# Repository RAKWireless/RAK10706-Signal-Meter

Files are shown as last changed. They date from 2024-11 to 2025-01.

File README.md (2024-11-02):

# RAK10706 Signal Meter
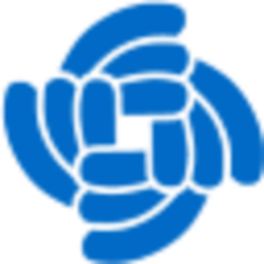
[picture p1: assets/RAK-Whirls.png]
RAKWireless
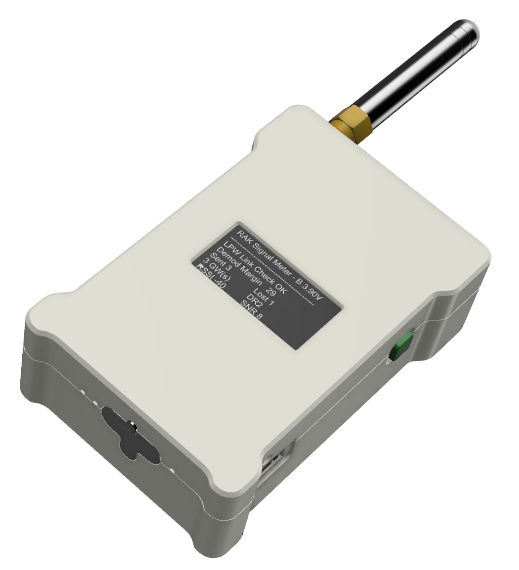
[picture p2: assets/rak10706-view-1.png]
Signal Meter
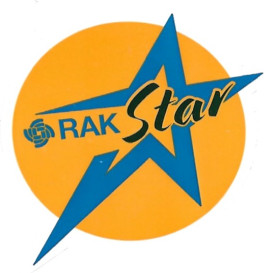
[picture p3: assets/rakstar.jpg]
RAKstar
|  |  |  | 
| :-: | :-: | :-: |

----

#### ⚠️ IMPORTANT ⚠️        
This firmware requires at least RUI3 V4.1.1 or newer.

#### ⚠️ ATTENTION ⚠️        
Requires the following Arduino libraries.

| Library | Get from Library Manager |
| --- | --- |
| ArduinoJSON version 6.x.x | http://librarymanager/All#ArduinoJson |
| SD | http://librarymanager/All#SD |
| Melopero RV3028 | http://librarymanager/All#RV3028 |
| Sparkfun LIS3DH | http://librarymanager/All#LIS3DH |
| Sparkfun u-Blox GNSS library | http://librarymanager/All#SparkFun_u-blox_GNSS |
| nRF OLED display | http://librarymanager/All#nRF52_OLED |
| CayenneLPP | http://librarymanager/All#CayenneLPP |

----

# Content
- [Overview](#overview)
- [Typical test scenarios](#typical-test-scenarios)
- [Custom AT commands](#custom-at-commands)
- [Hardware](#hardware)
- [Setup with built-in UI](#setup-with-built-in-ui)
- [Setup with AT commands](#setup-with-at-commands)
  - [LoRa P2P](#lora-p2p-setup)
  - [LoRaWAN LinkCheck](#lorawan-linkcheck-setup)
  - [LoRaWAN FieldTester (requires backend server)](#lorawan-field-tester-setup)
- [Usage](#usage)
  - [LoRa P2P](#lora-p2p)
  - [LoRaWAN LinkCheck](#lorawan-linkcheck)
  - [LoRaWAN FieldTester (requires backend server)](#lorawan-field-tester)
- [Log files (If SD card is present)](#log-files-if-sd-card-is-present)
  - [AT command for log files](#at-commands-for-log-files)
  - [Linkcheck mode log format](#linkcheck-mode-log-format)
  - [FieldTester mode log format](#field-tester-mode-log-format)
  - [P2P mode log format](#p2p-mode-log-format)
- [Enclosure](#enclosure)
- [Firmware](#firmware)

----

# Overview

The **RAK10706 Signal Meter for LoRa** is a basic signal meter. It works in both LoRa P2P and LoRaWAN mode. It uses an OLED display and a single-button controlled UI for settings changes. In addition, it can use an SD card to log the test results in CSV files. It is powered by a rechargeable battery and can be charged via USB Type-C interface.    
It uses an OLED display and a one-button controlled UI for settings changes. In addition, it can use an SD card to save the test results in .CSV files.   
All settings can be done as well over USB with RUI3 AT commands.    
It is a very easy to use device that can help to check LoRa and LoRaWAN coverage. It does not claim to be a super precise instrument, it is just an affordable small instrument to check signal coverage.    

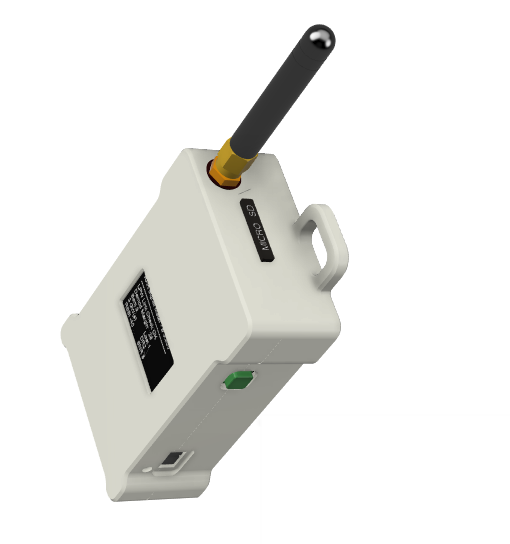
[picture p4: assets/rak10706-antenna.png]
Device internal
<center>Device&nbsp&nbsp&nbsp&nbsp</center>

#### ⚠️ INFO ⚠️        
One of the advantages of this simple tester is that it does not require any backend installations on the LoRaWAN server (like Helium, TTN and Chirpstack) if used in LinkCheck Packet mode, but should work with any LoRaWAN server like AWS or Actility.     
Only the FieldTester Mode requires a backend server.    

## LoRa P2P mode
If used in LoRa P2P, it is listening on the selected LoRa P2P settings and sending packets on the same settings:
- Frequency
- Bandwidth
- Spreading Factor
- Coding Rate
- Preample Length  

If a packet is received on above settings, it will display the information on the OLED screen. To use it for a specific P2P scenario, it will require adaption in the code, like recognizing packets, send out specific test packets to other LoRa P2P nodes.

## LoRaWAN mode
If used in LoRaWAN mode, the device is connecting to a LoRaWAN server and sends out frequently a data packet. 
It requires setup of the devices with its LoRaWAN credentials and register on a LoRaWAN server with
- DevEUI
- AppEUI
- AppKey
- OTAA join mode
- LoRaWAN region

### LoRaWAN Linkcheck test mode     
It uses LinkCheck to collect information about the connection to the gateway(s).    
With LinkCheck, the LoRaWAN server will report the number of gateways and the demodulation margin (calculated on the LoRaWAN server). The demodulation margin can give you information about the received signal quality (The higher the margin, the better the signal quality).     
Extract from the _**LoRaWAN 1.0.3 Specification**_:
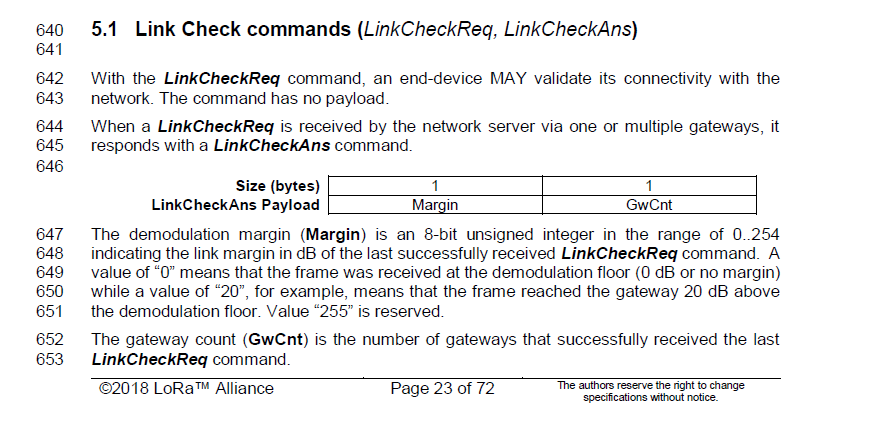
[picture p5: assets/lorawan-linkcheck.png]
LinkCheck


### LoRaWAN FieldTester test mode    
In addition, it supports the RAK10701 FieldTester protocol. The advantage of the FieldTester protocol is that it provides more information about the test, including distances to the gateways. The disadvantage is that this protocol requires a backend server to process the information and send it back to the device.

# Typical test scenarios
In all scenarios, tests can be performed in two ways:
- automatic sending in a specified interval. The interval can be set either through the built-in UI or with an AT command.
- forced sending. 3 times pushing the button enforces sending out a single packet in the pre-defined settings.
- forced sending with DR sweep (only in LoRaWAN test modes). 4 times pushing the button enforces multiple packets to be sent out. Sending starts with the lowest possible data rate and increases the data rate with each packet until the highest possible data rate has been reached.    

## Outdoor testing
In this scenario the location tracking should be enabled to add the tester location to the test results.    
The log files will contain the location of the tester at the time the test was performed. If no location fix could be acquired, the location will be set to Lat 0, Long 0.    

## Indoor testing
In this scenario the location tracking should be disabled, as the GNSS chip cannot aqcuire a valid location inside of buildings.    
The log files will not contain the location of the tester.

## LinkCheck testing
If it is not possible to connect a backend server to the LoRaWAN server to process the data of the received packets, the LinkCheck method should be used. It can deliver the basic information of the connection quality and if the tester is in the coverage range of gateways.

## FieldTester mode
If a backend server is connected to the LoRaWAN server that can process the data of the received packets, the FieldTester mode gives more details in the results of the test. 

## LoRa P2P testing
This is a very basic test that only shows whether the device is in range of another LoRa P2P device that is sending out packets.    

# Custom AT commands     
This examples includes multiple custom AT commands:     
- **`ATC+SENDINT`** to set the send interval time or heart beat time. The device will send a payload with this interval. The time is set in seconds, e.g. **`AT+SENDINT=600`** sets the send interval to 600 seconds or 10 minutes.    
- **`ATC+MODE`** to set the test mode. 0 using LPWAN LinkCheck, 1 using LoRa P2P, 2 using FieldTester protocol.
- **`ATC+STATUS`** to get some status information from the device.    
- **`ATC+PCKG`** to setup a custom payload that is used in the uplink packets.
- **`ATC+LOGS`** to retrieve or erase saved log files from the SD card (if SD card is present). See [AT command for log files](#at-commands-for-log-files)
- **`ATC+RTC`** to set or get time of RTC. Set format = [yyyy:mm:dd:hh:MM] (discard leading zeros!)

[Back to top](#content)

----

# Hardware
The device is built with a custom WisBlock Base Board:
- [WisBlock Base Board RAK19026 (WisMesh Base Board)](https://store.rakwireless.com/products/wismesh-baseboard-rak19026) ([Datasheet](https://docs.rakwireless.com/Product-Categories/Meshtastic/WisMesh-Base/Overview/))

To extend lifetime of the device, the battery can be disconnected by a simple slider switch. This helps to avoid discharging the battery while the device is not in use. The device can be charged, even with the button in off position!

The RAK19026 Base Board features as well a user configurable button, in this case it is used to control the UI, enable/disable the display and reset the device.

[Back to top](#content)

----

# Setup with built-in UI

Most of the parameters (not all) can be changed with the built-in UI.     
The UI has several levels, the navigation between the levels and selection of items is done with the single user button of the device.    

## Generic function of the button if the Settings UI is not active:

### Single click
==> no function

### Double click
==> enter the Settings UI (stops the testing mode, no more test packets are sent and received packets are ignored)

### 3 clicks
==> Force a downlink packet to be sent

### 4 clicks
==> Force multiple downlink packets with DR sweep. Sending starts with the lowest possible data rate and increases the data rate with each packet until the highest possible data rate has been reached.

### 5 clicks
==> no function (to avoid accidental reset of device)

### 6 clicks
==> Reset the device

### 7 clicks
==> Enter Bootloader Mode

### Long Press
==> switch off / on the display for power savings

## Function of the button if the Settings UI is active

The button function in the Settings UI changes, depending on the settings level. In general, a single click goes up one level in the settings.     
For other items, the number in front of the item indicates the number of clicks required to activate the level.    
If a level has selectable items, the selected items is marked with _**`(X)`**_ instead of its number.    
If a level has an item that can be toggled on/off, the status is shown after the item name.    

Overview of all settings levels and button functions:

| Level | Sub Level 1 | Sub Level 2 | Comment |
| ----- | --- | --- |--- |
| Top level<br> | | | Device might reset on leaving the settings if test mode has changed. |
| | Device Info <br> | | Current test settings |
| | Device Settings <br> | | General settings<br> Location and Display Saver are on/off toggle items<br><br>- Location on works only in FieldTester Mode and keeps the GNSS module powered up for faster location acquisition (faster battery drain)<br><br>- Display Saver on switches off the display after 1 minute. The display can be turned on with a single button click. |
| | | Send Interval <br> | Change send interval in 10 second steps<br>(2) 10 seconds more<br>(3) 10 seconds less |
| | Mode <br> | | Exclusive selection of one mode by number of clicks |
| | LoRa Settings (LoRaWAN test modes) <br> | | UI depends on selected test mode.<br> In LinkCheck, Confirmed Packet and FieldTester Mode, it shows LoRaWAN specific settings. |
| | | ADR on/off<br> | Switch ADR on or off |
| | | DR selection<br> | Change DR setting<br> (2) next higher DR<br>(3) next lower DR |
| | | TX Power selection<br> | Change TX power setting<br> (2) next higher TX power<br>(3) next lower TX power |
| | | LoRaWAN region selection<br> | Change LoRaWAN region setting<br> (2) next region<br>(3) previous region |
| | LoRa Settings (LoRa P2P test mode) <br> | | UI depends on selected test mode.<br> In LoRa P2P Mode, it shows LoRa P2P specific settings. |
| | | Frequency change<br> | Change send/receive frequency<br>(2) 0.1MHz up<br>(3) 0.1MHz down<br>For larger changes, it is recommended to use the AT commands. |
| | | SF change<br> | Change Spreading Factor<br>(2) next SF<br>(3) previous SF<br>For larger changes, it is recommended to use the AT commands. |
| | | BW change<br> | Change Bandwidth<br>(2) next BW<br>(3) previous BW |
| | | CR change<br> | Change Coding Rate<br>(2) next CR<br>(3) previous CR |
| | | TX power change<br> | Change Transmission Power<br>(2) next TX level <br>(3) previous TX level |

----

# Setup with AT commands

## LoRa P2P Setup

To use the device in LoRa P2P mode it has to be set into this mode with     
```at
AT+NWM=0
```
The device might reboot after this command, if it was not already in P2P mode.    
Then the LoRa P2P parameters have to be setup. In this example, I am setting the device to 916100000 Hz frequency, 125kHz bandwidth, spreading factor 7, coding rate 4/5, preamble length 8 and TX power of 5dBm:

```at
AT+PRECV=0
AT+P2P=916000000:7:0:1:8:5
ATC+MODE=2
```

#### ⚠️ TIP ⚠️ 
If the credentials were set already (they are saved in the flash of the device), the switch to P2P testing can as well be done with
```at
ATC+MODE=2
```
The device might reboot after this command, if it was not already in LoRa P2P mode.    

#### ⚠️ TIP ⚠️        
The command _**`AT+PRECV=0`**_ is _**required**_ to stop the device from listening. While in RX mode, parameters cannot be changed.

To be able to receive packets from other devices, they have to be setup to exactly the same parameters.

[Back to top](#content)

----

## LoRaWAN LinkCheck Setup

To use the device in LoRaWAN mode it has to be set into this mode with     
```at
AT+NWM=1
```
The device might reboot after this command, if it was not already in LoRaWAN mode.    
Then the LoRaWAN parameters and credentials have to be setup. In this example, I am setting the device to AS923-3, OTAA join mode, unconfirmed packet mode, enable link check and then reset the device to perform a LoRaWAN JOIN sequence:

```at
AT+BAND=10
AT+NJM=1
AT+CFM=0
AT+LINKCHECK=2
AT+DEVEUI=AC1F09FFFE000000
AT+APPEUI=AC1F09FFFE000000
AT+APPKEY=AC1F09FFFE000000AC1F09FFFE000000
ATC+MODE=0
ATZ
```

#### ⚠️ TIP ⚠️ 
If the credentials were set already (they are saved in the flash of the device), the switch to LinkCheck testing can as well be done with
```at
ATC+MODE=0
```
The device might reboot after this command, if it was not already in LoRaWAN mode.    

#### ⚠️ IMPORTANT ⚠️        
The device has to be registered in a LoRaWAN server with these credentials and a gateway in range has to be connected to the LoRaWAN server. Otherwise the device cannot join and there are no tests possible!
If the device cannot join the network, it will show an error on the display:

<center>LoRaWAN Join Failed</center>

In this case double check all settings on the device and LoRaWAN server and check if a gateway is in range and connected to the LoRaWAN server.

[Back to top](#content)

----

## LoRaWAN FieldTester Setup

To use the device in LoRaWAN mode it has to be set into this mode with     
```at
AT+NWM=1
```
The device might reboot after this command, if it was not already in LoRaWAN mode.    
Then the LoRaWAN parameters and credentials have to be setup. In this example, I am setting the device to AS923-3, OTAA join mode, confirmed packet mode, disable link check and then reset the device to perform a LoRaWAN JOIN sequence:

```at
AT+BAND=10
AT+NJM=1
AT+CFM=1
AT+LINKCHECK=0
AT+DEVEUI=AC1F09FFFE000000
AT+APPEUI=AC1F09FFFE000000
AT+APPKEY=AC1F09FFFE000000AC1F09FFFE000000
ATC+MODE=3
ATZ
```

#### ⚠️ TIP ⚠️ 
If the credentials were set already (they are saved in the flash of the device), the switch to FieldTester testing can as well be done with
```at
ATC+MODE=3
```
The device might reboot after this command, if it was not already in LoRaWAN mode.    

#### ⚠️ IMPORTANT ⚠️        
In FieldTester Mode a backend server has to be setup as integration in the LoRaWAN server. Without this backend server, the FieldTester Mode does not work.    
More information about available backend solutions can be found in the [RAK10701 documentation](https://docs.rakwireless.com/Product-Categories/WisNode/RAK10701-P/Quickstart/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)

#### ⚠️ IMPORTANT ⚠️        
The device has to be registered in a LoRaWAN server with these credentials and a gateway in range has to be connected to the LoRaWAN server. Otherwise the device cannot join and there are no tests possible!
If the device cannot join the network, it will show an error on the display:

<center>LoRaWAN Join Failed</center>

In this case double check all settings on the device and LoRaWAN server and check if a gateway is in range and connected to the LoRaWAN server.

[Back to top](#content)

----

# Usage
The principle usage for all modes is similar. After selecting the mode and setting the correct parameters and credentials, the device will send uplink packets in the selected send interval.    

#### ⚠️ IMPORTANT ⚠️        
When using FieldTester Mode, the device requires to have a valid location fix from it's builtin GNSS module. Otherwise it will not send any uplink packets.    

## LoRa P2P

If the setup of all devices is the same and a packet is received, the display will show the received LoRa P2P packets:

- P2P received packet number
- Frequency, spreading factor and bandwidth
- RSSI
- SNR

<center>LoRa P2P</center>

[Back to top](#content)

----

## LoRaWAN LinkCheck

After the device has joined the network, it will send unconfirmed packets with LinkCheck request enabled to the LoRaWAN server. The LoRaWAN server will answer to the LinkCheck request. The display will show
- Linkcheck result
- Packet number and number of gateways
- DR of the received packet
- RSSI and SNR of the received packet
- Demodulation Margin from the LoRaWAN server

<center>LoRaWAN ACK</center>

If the device is out of the range of gateways (after it had joined before), it will show an error message if the LoRaWAN server did respond to the LinkCheck request:
- Linkcheck result
- Number of lost packets

<center>LoRaWAN ACK</center>

[Back to top](#content)

----

## LoRaWAN FieldTester

After the device has joined the network, it will send confirmed packets with location information to the LoRaWAN server. The LoRaWAN server will forward this information together with gateway information to the backend server. The backend server will create and send a downlink packet to the tester. The display will show
- RSSI and SNR level of the received downlink packet
- Number of gateways that received the packet
- Min and Max RSSI levels seen by the gateways
- Min and Max calculated distance between the tester and the gateways
- Location of the device

<center>Fieldtester display</center>

Before sending a uplink packet, the tester will try to acquire a location.    

<center>Fieldtester location acquisition</center>

If a location fix can be acquired, it will send an uplink packet, then wait for the downlink packet from the backend server:

If no location fix can be acquired, an error will be displayed and no packet will be sent:

<center>Fieldtester location failure</center>

#### ⚠️ IMPORTANT ⚠️        
In FieldTester Mode a backend server has to be setup as integration in the LoRaWAN server. Without this backend server, the FieldTester Mode does not work.    
More information about available backend solutions can be found in the [RAK10701 documentation](https://docs.rakwireless.com/Product-Categories/WisNode/RAK10701-P/Quickstart/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)

[Back to top](#content)

----

# Log files (If SD card is present)

If a SD card is present, the results of the coverage tests are written in CSV format to the SD card.    
The files start from 0000-log.csv and on every restart a new file with an upcounting number is created.    

## AT commands for log files

_**`ATC+LOGS=?`**_ is used to retrieve the log files over the USB port. This makes it possible to read the log files without removing the SD card from the device.    

_**`ATC+LOGS=e`**_ is used to erase all log files from the SD card.    

----

## Linkcheck mode log format

When in Linkcheck mode for LoRaWAN, the log file has the following format:    

### If location is enabled

time;Mode;Gw;Lat;Lng;RX RSSI;RX SNR;Demod;TX DR;Lost

### If location is disabled

time;Mode;Gw;RX RSSI;RX SNR;Demod;TX DR;Lost

| time | Mode | Gw | Lat | Lng | RX RSSI | RX SNR | Demod | TX DR | Lost |
| ---  | ---  | --- | --- | --- | --- | --- | --- | ---  | ---  |
| Time stamp (available if LNS has provided the time or if a RTC module is attached) | 0 for LinkCheck mode | Number of gateways | Latitude (if location is active and location fix) | Longitude (if location is active and location fix) | RSSI of downlink | SNR of downlink | demod value | TX datarate | number of lost packets  |
| 2024-10-07 14:35:20 | 0 | 1 | 14.521355 | 121.106880 | -91 | 8 | 29 | 3 |0  |

----

## FieldTester mode log format

When in FieldTester mode for LoRaWAN, the log file has the following format:    

time;Mode;Gw;Lat;Lng;min RSSI;max RSSI;RX RSSI;RX SNR;min Dist;max Dist; TX DR

| time | Mode | Gw | Lat | Lng | min RSSI | max RSSI | RX RSSI | RX SNR | min Dist | max Dist | TX DR |
| ---  | ---  | --- | --- | --- | --- | --- | --- | --- | --- | --- | --- |
| Time stamp (available if LNS has provided the time or if a RTC module is attached) | 2 for FieldTester mode | Number of gateways | Latitude (can be 0.0 if no location fix, e.g. indoor testing) | Longitude (can be 0.0 if no location fix, e.g. indoor testing) | min RSSI seen by gateways | max RSSI seen by gateways | RSSI of downlink | SNR of downlink | min distance to gateway(s) | max distance to gateway(s) | TX datarate |
| 2024-10-07 14:39:00 | 2 | 1 | 14.521355 | 121.106880 | -50 | -50 | -59 | 7 | 250 | 250 | 5 |

----

## P2P mode log format

When in Linkcheck mode for LoRaWAN, the log file has the following format:    

### If location is enabled

time;Mode;Lat;Lng;RX RSSI;RX SNR

### If location is disabled

time;Mode;RX RSSI;RX SNR

| time | Mode | Lat | Lng | RX RSSI | RX SNR |
| ---  | ---  | --- | --- | --- | --- |
| Time stamp (available if LNS has provided the time or if a RTC module is attached) | 1 for LinkCheck mode | Latitude (if location is active and location fix) | Longitude (if location is active and location fix) | RSSI of downlink | SNR of downlink |
| 2024-10-07 14:51:21 | 1 | 14.521355 | 121.106880 | -38 | 12 |

----

# Enclosure

The enclosure is 3D printed and kept as simple as possible. Two main parts are needed. The bottom and the lid are sliding into each other to give a basic dust protection and are secured with four screws.    
In addition three smaller parts are used to give a dust protection to the user button, power switch and reset button. The LED's and the OLED screen can be protected by adding a thin transparent plastic foil.    
For the USB port and SD card slot rubber lids are used.    

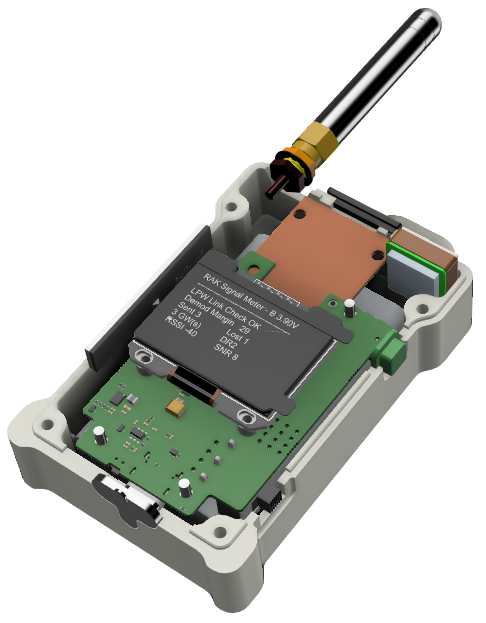
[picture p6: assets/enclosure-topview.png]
Enclosure Top View


The OLED display is part of the Base Board.    

The top and bottom part of the enclosure are overlapping to provide a simple sealing.

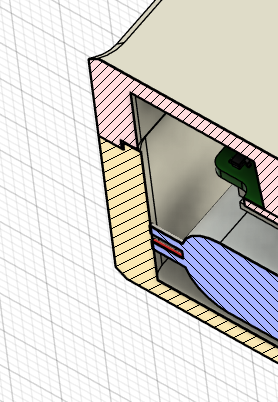
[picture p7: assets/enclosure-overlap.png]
Enclosure Sealing
    

The button of the RAK19026 is protected with additional 3D parts (green) against dust entry.

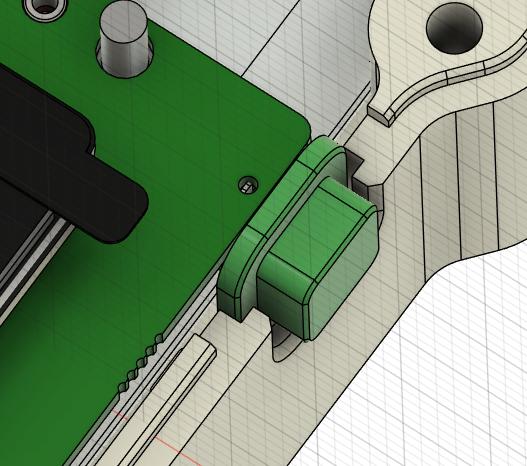
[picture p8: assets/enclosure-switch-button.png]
Enclosure Switch and Button
    

The enclosure provides enough space for a 3200mAh Li-Ion battery glued to the bottom.

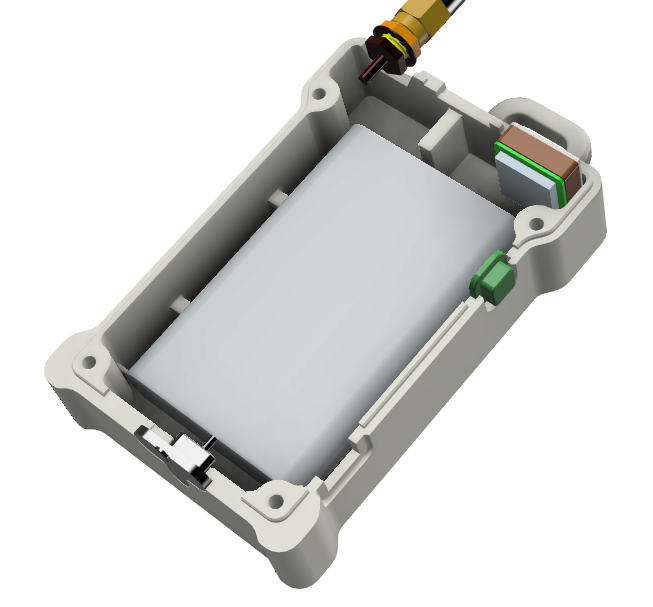
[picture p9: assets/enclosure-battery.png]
Enclosure Screws


#### ⚠️ TIP ⚠️        
The 3D files for the enclosure are available in this repository in the folder [enclosure](./enclosure) 

[Back to top](#content)

----

# Firmware

The firmware for this Signal Meter is available in this repository.

Callbacks are defined for all possible events, both LoRa P2P and LoRaWAN and trigger the display to change its content.

The **`setup()`**` function is checking in which mode the device is setup and initializes the required event callbacks.

The application is complete timer triggered and the **`loop()`** function is only used when the user button is used to check the number of clicks or to detect a long press of the button.

## LoRa P2P callbacks

```cpp
/**
 * @brief Receive callback for LoRa P2P mode
 *
 * @param data structure with RX packet information
 */
void recv_cb_p2p(rui_lora_p2p_recv_t data)
{}
```

## LoRaWAN callback

```cpp
/**
 * @brief Join network callback
 * 
 * @param status status of join request
 */
void join_cb_lpw(int32_t status)
{}

/**
 * @brief Receive callback for LoRaWAN mode
 *
 * @param data structure with RX packet information
 */
void recv_cb_lpw(SERVICE_LORA_RECEIVE_T *data)
{}

/**
 * @brief Send finished callback for LoRaWAN mode
 *
 * @param status
 */
void send_cb_lpw(int32_t status)
{}

/**
 * @brief Linkcheck callback
 * 
 * @param data structure with the result of the Linkcheck
 */
void linkcheck_cb_lpw(SERVICE_LORA_LINKCHECK_T *data)
{}
```

## LoRaWAN send
This function sends a short LoRaWAN packet in confirmed or unconfirmed mode, depending whether LinkCheck is enabled or not
```cpp
/**
 * @brief Send a LoRaWAN packet
 *
 * @param data unused
 */
void send_packet(void *data)
{
	Serial.println("Send packet");
	uint8_t payload[4] = {0x01, 0x02, 0x03, 0x04};

	api.lorawan.send(4, payload, 2, false);
	tx_active = true;
	}
}
```

## Display handler
The display handler callback includes a flag that tells what kind of display content should be displayed.
```cpp
/**
 * @brief Display handler
 *
 * @param reason 1 = RX packet display
 *               2 = TX failed display (only LPW mode)
 *               3 = Join failed (only LPW mode)
 *               4 = Linkcheck result display (only LPW LinkCheck mode)
 *               5 = Join success (only LPW mode)
 *               6 = FieldTester downlink packet
 */
void handle_display(void *reason)
{}

```
[Back to top](#content)

----

----
----

# LoRa® is a registered trademark or service mark of Semtech Corporation or its affiliates. 

# LoRaWAN® is a licensed mark.

----
----

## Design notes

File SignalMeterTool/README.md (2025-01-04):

# Signal Meter Tool
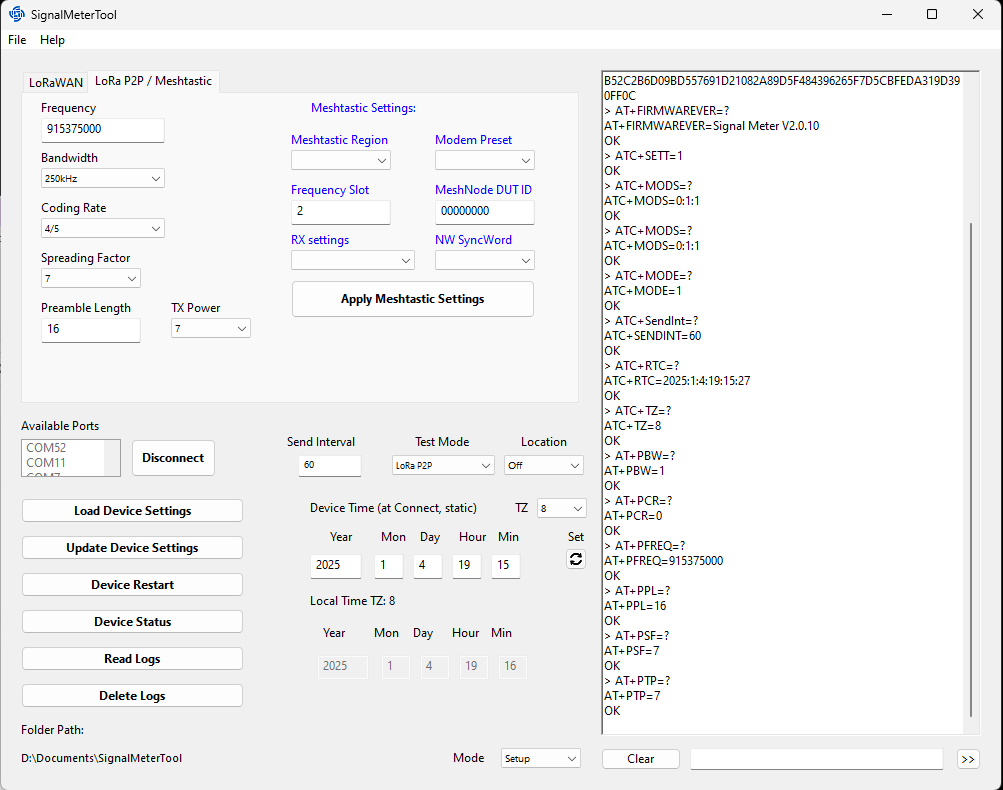
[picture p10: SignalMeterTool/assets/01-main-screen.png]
Signal Meter
| RAKWireless |  | RAKstar | 
| :-: | :-: | :-: |

Signal Meter Tool is an application to setup a RAK10706 without the hassle of sending AT commands from a Serial Terminal Application.    
#### ⚠️ IMPORTANT ⚠️
#### _**This is not an official RAKwireless application!**_      
It was written in my free time and has no official support from RAKwireless.    
It is not fully tested and still has bugs.     
It is tested on Windows 11, on a Linux Ubuntu 24.04 based VM (automatic reconnection doesn't work in the VM) and should work on macOS ????????? (not tested by me).    
It has some experimental support to be used as Meshtastic Signal Tester, but this feature is work in progress.

# Installation 

## Windows
For Windows 11 an application installer is in the [SignalMeterTool/Windows](./Windows/) folder.     
Virus scanner will most likely complain about it, as it is not a signed Windows application.

## Linux
For Ubuntu 24.04 download the content of the [SignalMeterTool/Linux](./Linux) folder.     

#### ⚠️ IMPORTANT ⚠️
It might be required to add your user to the _**`dialout`**_ group to get access to the USB ports of the Linux Machine.    
Another requirement might be to give the user access to the folder where the application was saved.
```shell
sudo usermod -a -G dialout $USER

sudo chown -R $USER ./SignalMeterTool
```

## macOS
For macOS download the content of the [SignalMeterTool/macOS](./macOS) folder.     

#### ⚠️ IMPORTANT ⚠️
I have no machine with macOS and could not test the installation procedure or the application itself

----

# Usage
After installation, start the application. The UI is separated into 6 parts.    
1. Serial Ports, Connect/Disconnect button, Load Device Settings, Update Device Settings, option to restart the device and to see current device settings in the log output 
2. LoRa P2P and LoRaWAN settings
3. Test mode settings
4. Buttons to read or delete log files _**(only available if the device is equipped with an SD card)**_
5. Functions to setup the RTC and the timezone _**(only available if the device is equipped with a RTC module)**_    

In addition there are 3 parts for debugging.     

6. Log output of the communication with the device. It can be used as well to send manual AT commands.        
7. Switching the tool function from device setup mode to debug mode, where the device will start its test mode and the log output will show information.    

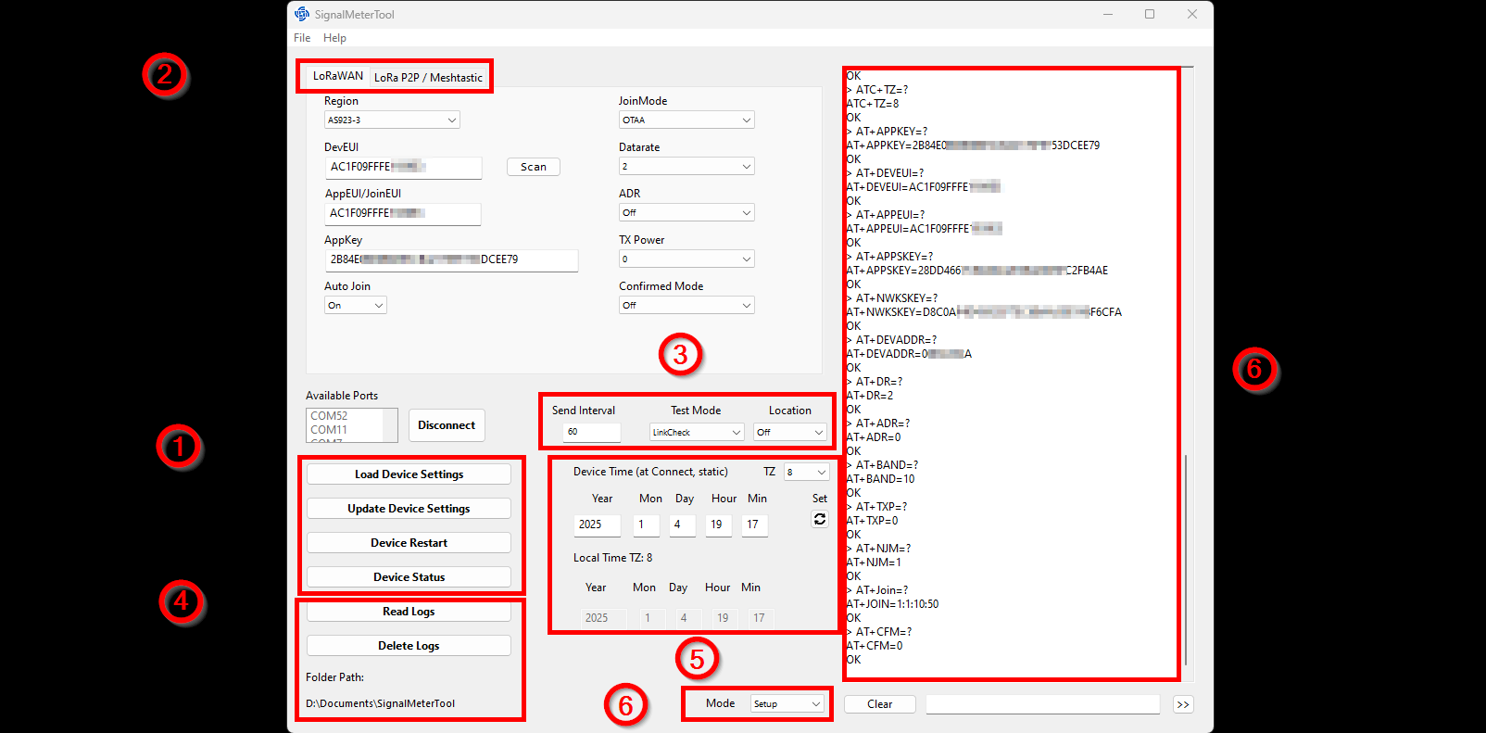
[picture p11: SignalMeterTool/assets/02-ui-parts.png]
UI


## Connect to the device

Check the available devices in the **Available Ports** list box. To find the correct port where the RAK10706 is connected, start the application first, then plug in the device into the USB port.    
The list box will be automatically updated with the new device, which will be the RAK10706.     

<center>Port selection</center>

Once you have selected the port, push **Connect** to establish a connection to the device.     
     
Once connected, Use the **Load Device Settings** button to read the current settings from the RAK10706. This can take a while and you will see a red **Busy** wheel next to the **Connect** button.     

#### ⚠️ Potential errors during connection ⚠️
1. No port or an invalid port was selected
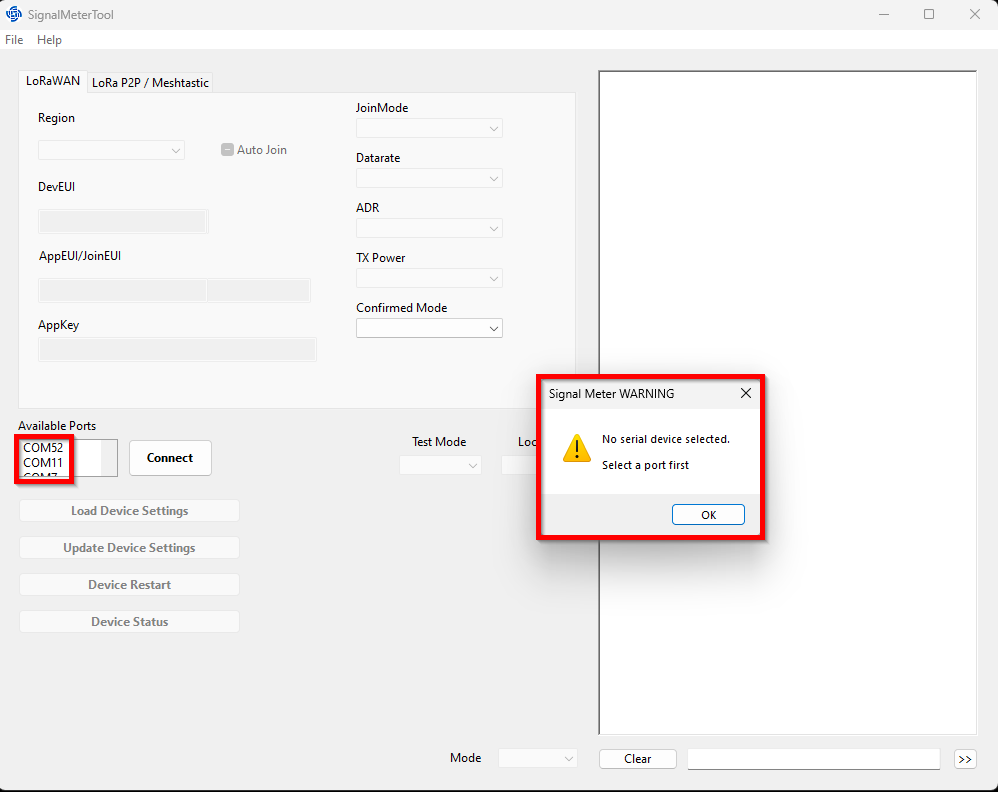
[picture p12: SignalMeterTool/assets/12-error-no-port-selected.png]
Port error
     

In this case, select a port from the list box.     

#### ⚠️ Potential errors while loading the device settings ⚠️

1. Device is not a RAK10706 device
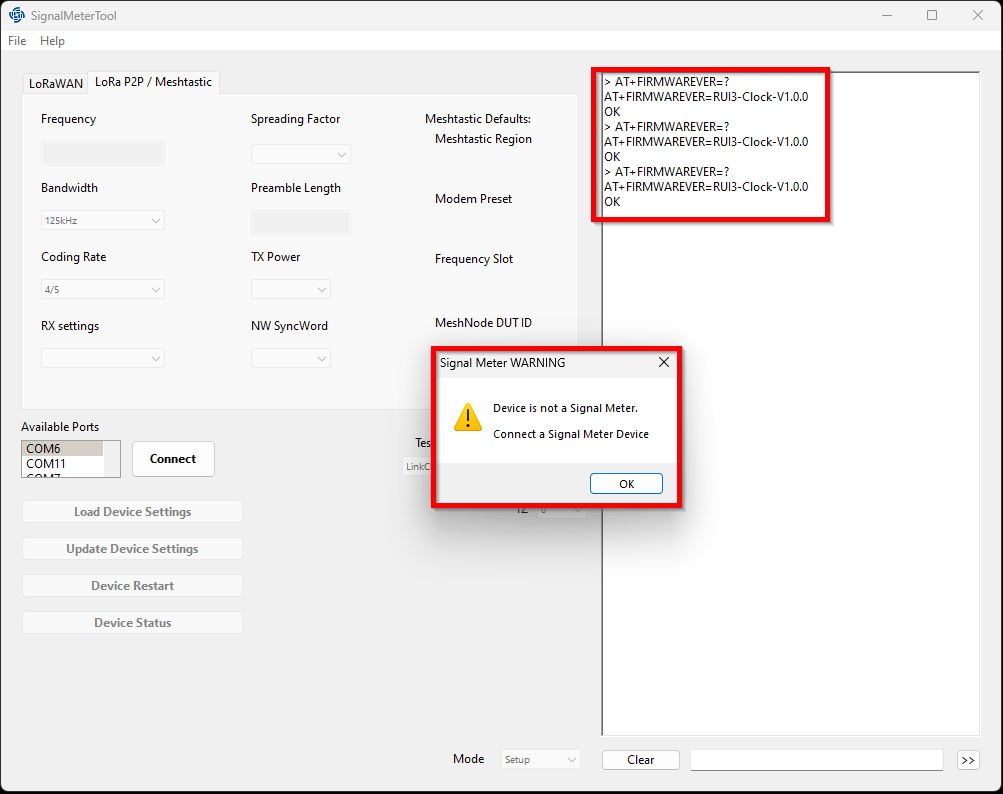
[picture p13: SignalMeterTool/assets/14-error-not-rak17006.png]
Not a RAK10706
     

This error will show when Load Device Settings is clicked, but the connected device is not a RAK10706.    This application does only work with the RAK10706 Signal Meter for LoRa!

2. A communication error occured    
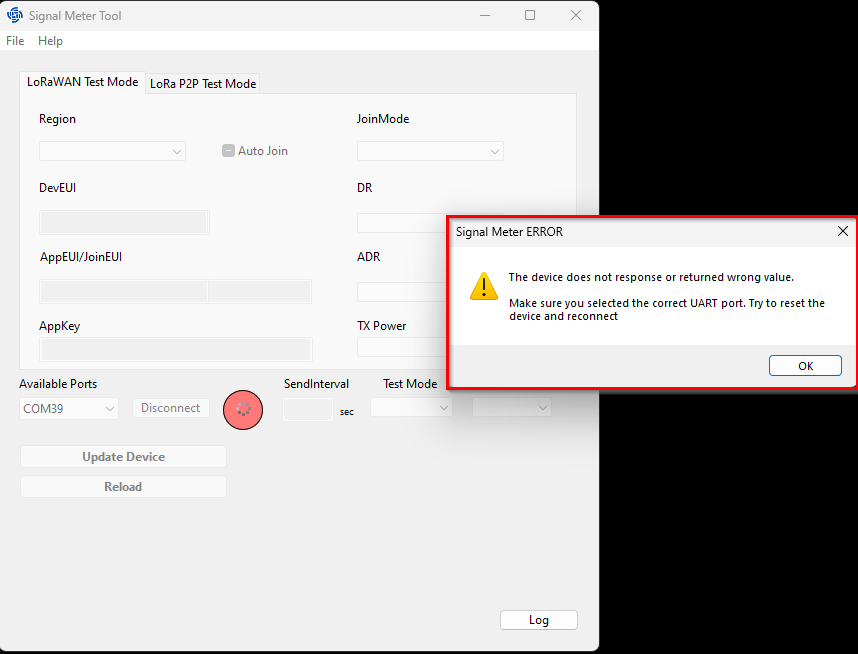
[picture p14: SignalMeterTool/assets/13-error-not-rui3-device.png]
Communication error
     

The device does not support RUI3 AT commands or a communication error occured during fetching the device settings. In this case, disconnect the device and restart the application. Make sure the device you are connecting to is a RAK10706 Signal Meter for LoRa.

----

## Load device settings

After connecting the device, the _**Load Device Settings**_ button will load the current settings from the device. 

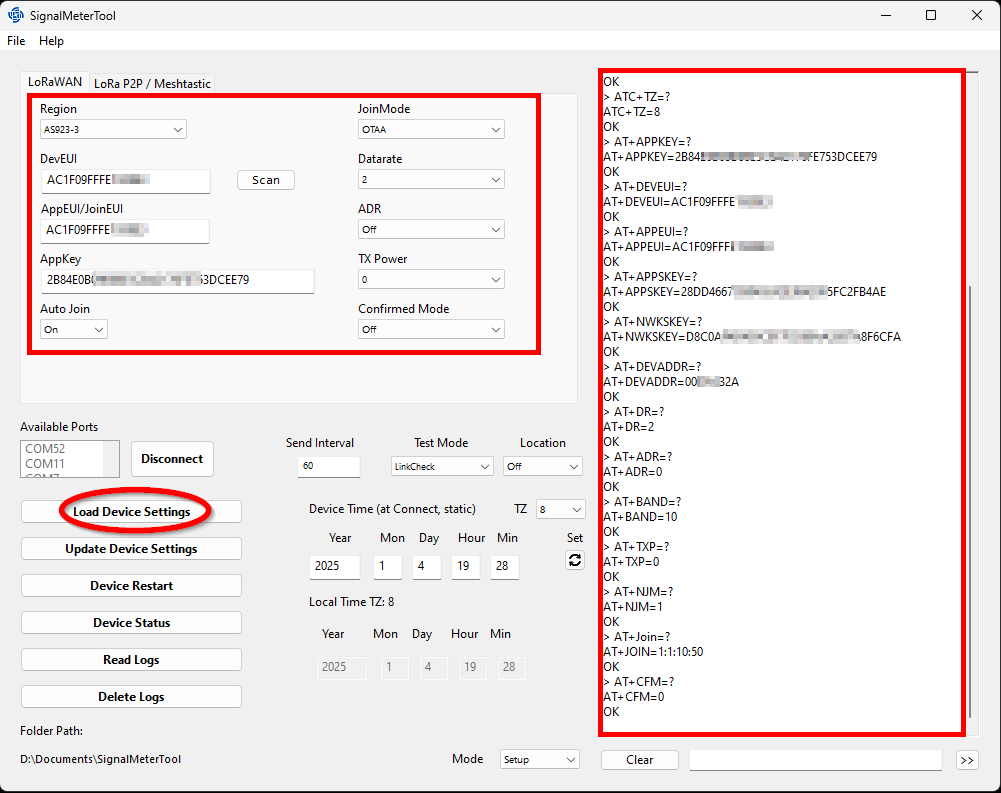
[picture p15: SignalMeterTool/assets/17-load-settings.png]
Load device settings
     

#### ⚠️ Occasionally the application can hang while reading the current settings ⚠️    
In this case, disconnect the device and restart the application.    
The reason for this bug is still under investigation.

## Application UI after successful connection

After a successful sync with the device, the UI will change, depending on the current settings of the device and the available modules.     

### LoRaWAN test modes
If the device is in a test mode that is using LoRaWAN (LinkCheck or Field Tester modes), the UI will show the LoRaWAN credentials and LoRaWAN settings.    
Independent of the Join Mode, the following settings can be set:

1. Region → Select the LoRaWAN region that device will be used with.
2. DR → Set the data rate that will be used for the testing.
3. TX Power → Set the TX Power that will be used for the testing.
4. ADR → Enable or disable the automatic data rate adaption.     
⚠️ _**During testing, it is recommended to disable ADR to get usable test results**_
5. JoinMode → Change the join mode between OTAA and ABP. _**The change will only be applied after the device settings are updated and the device rebooted!**_
6. Automatic Network Join → The device will automatically join the network after power-up.    
⚠️ _**It is essential to enable the automatic network join on the Signal Meter before using it**_

Depending on the LoRaWAN Join mode, the device credentials will be different:

----

#### LoRaWAN in join mode OTAA

In OTAA mode, the UI will show the DevEUI, AppEUI (JoinEUI) and the AppKey:

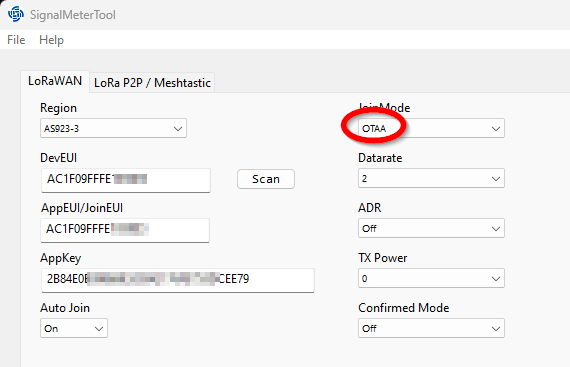
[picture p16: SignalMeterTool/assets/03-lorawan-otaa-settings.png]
LoRaWAN OTAA settings
     

The credentials can be copied from the application and used to register the device in a LoRaWAN server. Or, if preferred, the credentials can be set to values that are provided by a LoRaWAN server.    

----

#### LoRaWAN in join mode ABP

In ABP mode, the UI will show the DevEUI, AppEUI (JoinEUI) and the AppKey:

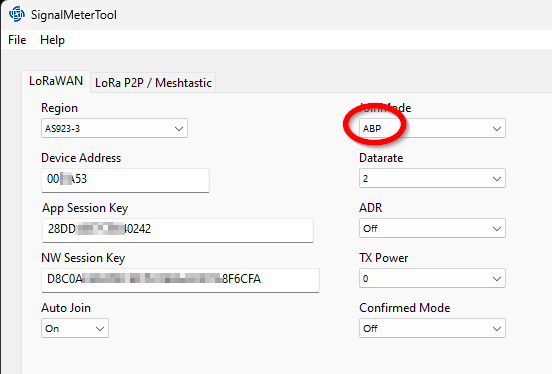
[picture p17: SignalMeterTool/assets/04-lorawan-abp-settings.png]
LoRaWAN ABP settings
     

The credentials can be copied from the application and used to register the device in a LoRaWAN server. Or, if preferred, the credentials can be set to values that are provided by a LoRaWAN server.    

----

### LoRa P2P test mode
If the device is in LoRa P2P test mode, the UI will show the LoRa P2P (Phy) settings. These settings must be identical to the LoRa P2P network that other LoRa nodes in the test are using:

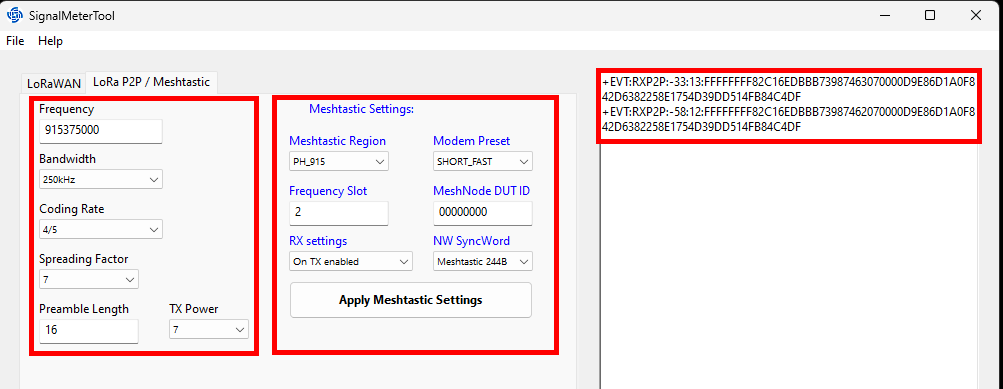
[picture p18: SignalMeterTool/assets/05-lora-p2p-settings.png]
LoRaWAN P2P settings
     

#### ⚠️ Information
The device setup supports only LoRa mode, it is not possible to setup the device to FSK mode. If this is required, it has to be done with AT commands.     

#### ⚠️ Experimental Meshtastic support
In the right side of the P2P test mode, settings for the Meshtastic network can be found.    
After selecting the Meshtastic Region, the Modem Preset and the Frequency Slot, the _**Apply Settings**_ button will set the P2P parameters for these Meshtastic settings.    

_The RAK10706 can only listen to Meshtastic data packets. It cannot decode the content. But the basic information received can show if the RAK10706 is in coverage range of the Meshtastic network and the signal quality of the received packets._    
It is _**NOT**_ possible to send packets to Meshtastic nodes.    
To test the range of a specific Meshtastic device, the Meshnode DUT ID can be setup, then the RAK10706 will only show information about received packets from this specific Meshtastic Node.    
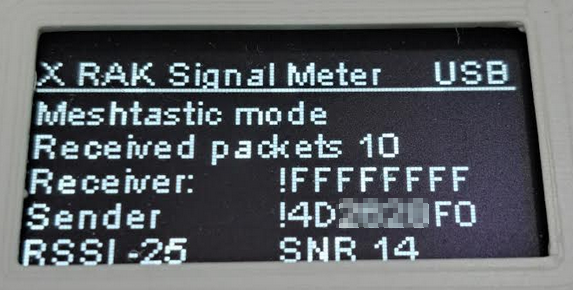
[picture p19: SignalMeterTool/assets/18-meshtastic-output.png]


#### ⚠️ Experimental Meshtastic support

----

### Send Interval, Test Mode and Location

This section of the UI allows to change the send interval, select the test mode and enable or disable the location tracking mode.    

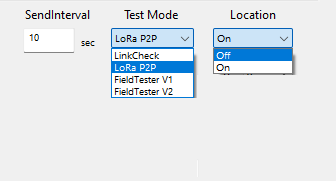
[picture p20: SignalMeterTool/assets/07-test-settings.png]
Test settings
 

----

#### Send Interval
The send interval defines the time between sending test packets. The value is set in seconds. _**Values below 10 seconds are not recommended for test modes that are using LoRaWAN. If set too short, the downlink packets from the LoRaWAN server might not be received.**_

----

#### Test Mode selection
Four different test modes are available on the RAK10706 Signal Meter. Three of them are working in LoRaWAN mode, one is for LoRa P2P.    
For differences between the test modes, check the [RAK10706 Quick Start Guide's](https://docs.rakwireless.com/product-categories/wisnode/rak10706/quickstart) and [differences between the RAK10706 Signal Meter and the RAK10701 Field Tester](https://docs.rakwireless.com/product-categories/wisnode/rak10706/quickstart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) section.

#### ⚠️ Important
Changing the test mode, will immediately reboot the device and set it to the new selected test mode.

----

#### Location
Depending on the test scenario (indoor or outdoor) it is possible to enable or disable the location module of the Signal Meter. 
An overview of different test scenarios are in the [RAK10706 Quick Start Guide's](https://docs.rakwireless.com/product-categories/wisnode/rak10706/quickstart#typical-test-scenarios) _**Typical Test Scenarios**_ section.

#### ⚠️ Important
Testing with the location tracking disabled does increase the life-time of the battery and is recommended if not absolute required.

----

### Load and Update Device Settings

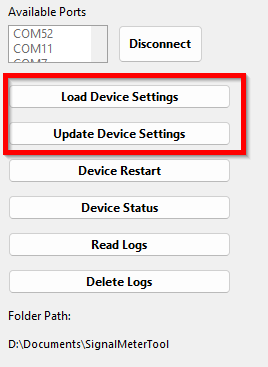
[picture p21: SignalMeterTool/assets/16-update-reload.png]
 

----

#### Load

The _**Load Device Settings**_ button will load the current device settings and update the UI of the application.    

#### ⚠️ Important
Most changes in the settings are sent immediately to the device. Reloading the settings will not recover the original settings of the device.    

----

#### Update Device

Once device settings are changed, the changes can be synced to the Signal Meter using the _**Update Device**_ button.

#### ⚠️ Important
Most changes in the settings are sent immediately to the device. The exception are the LoRaWAN credentials for both OTAA and ABP mode.    

----

### Reading and Deleting Log Files

#### ⚠️ Important
These functions are only enabled if the RAK10706 SignalMeter is equipped with an SD card.

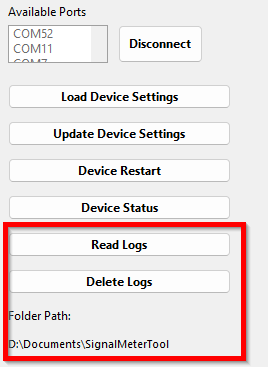
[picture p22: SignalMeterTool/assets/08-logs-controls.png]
Log file controls
 

----

#### Reading Logs

#### ⚠️ Important
_**Downloading the log files over the USB connection can take a very long time, depending on the size and number of log files stored on the SD card. It is recommended to remove the SD card from the device instead and copy the log files directly on a computer**_

Using the _**Read Logs**_ button will start the transfer of all log files from the SD card to the computer over the USB connection.     
The log files are in .CSV (comma separated values) format and can be read for further processing from most spreadsheet applications.    
The log files are saved in the folder shown below the button in the _**Folder Path:**_ section. Each reading of the log files will create a new sub folder in this path with the date and time the readings are started.

Log files top folder:

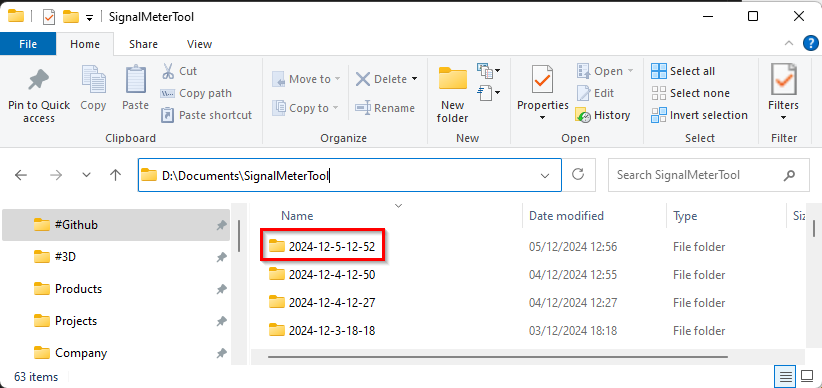
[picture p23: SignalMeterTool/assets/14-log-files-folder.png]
Log files folder
     

Log files:

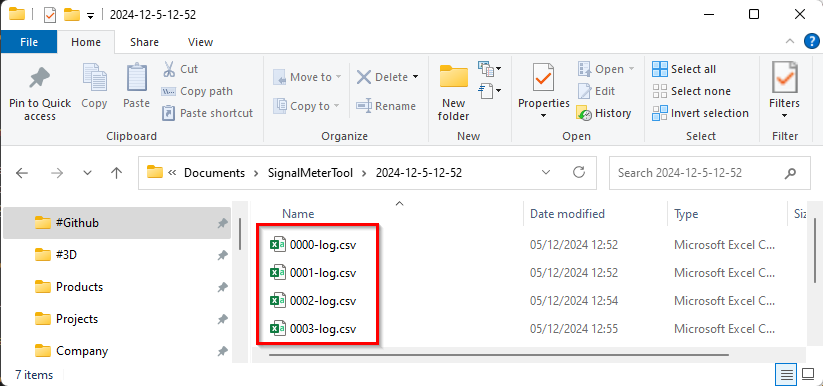
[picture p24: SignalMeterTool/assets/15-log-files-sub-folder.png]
Log files
     

#### ⚠️ Important
After reading the log files is finished, the device will be rebooting!

----

#### Delete Logs

Using the _**Delete Logs**_ button will erase all saved log files from the SD card. After using this button, the log files can not be recovered any more.

#### ⚠️ Important
After deleting the log files is finished, the device will be rebooting!

----

#### Device Restart and Device Status

The _**Device Restart**_ button will force a reboot of the device, if desired.    

The _** Device Status**_ will get the current device settings and display them in the log file. It does not change the settings in the UI!    

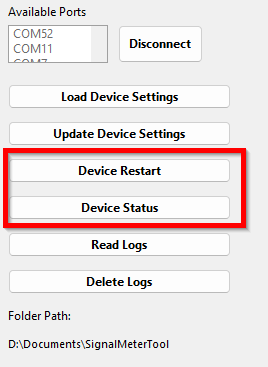
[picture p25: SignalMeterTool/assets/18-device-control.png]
 

----

### Setting the RTC and the Time Zone

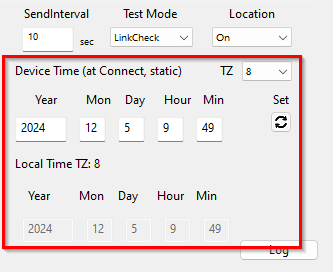
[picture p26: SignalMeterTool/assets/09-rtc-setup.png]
 

----

#### Setting the Time Zone

The device will synchronize its internal time with the LoRaWAN server time it is connected to. However the LoRaWAN server is sending the time in GMT+0 format. The device time is used in the log files, therefor it is important to set the correct Time Zone in which the device is used. Otherwise the date and time entries in the log files will be in GMT+0 format.

#### ⚠️ Important
_**It is essential to set the time zone the device will be used in to have the correct date and time in the log files**_

----

#### Setting the RTC module

#### ⚠️ Important
This function is only enabled if the RAK10706 SignalMeter is equipped with an RTC module.

The RTC module in the RAK10706 Signal Meter has a small back-up battery that can ensure that the time is kept accurate if the device is switched of for 1-2 weeks. But if the Signal Meter is not used over a longer time, the RTC will loose its time. The _**Set**_ button allows to synchronize the RTC time with the time of the connected computer.

----

### Communication Debug

The log window on the right side will show the communication between the SignalMeterTool and the device. It is helpful only for debug purposes.    

In addition it has a input window, where AT commands can be sent to the device for additional changes, that are not supported by the tool.    

The _**Clear**_ button deletes all lines from the log window.    

Using the _**Mode**_ selector, the tool can be switched between _Setup_ and _Debug_ mode. While in _**Setup**_ mode, the device does not perform range testing. Switching to _**Debug**_ mode, enables the test sequence on the device and it will show some debug information in the log window.. This can be helpful to find problems with the SignalMeterTool application.    

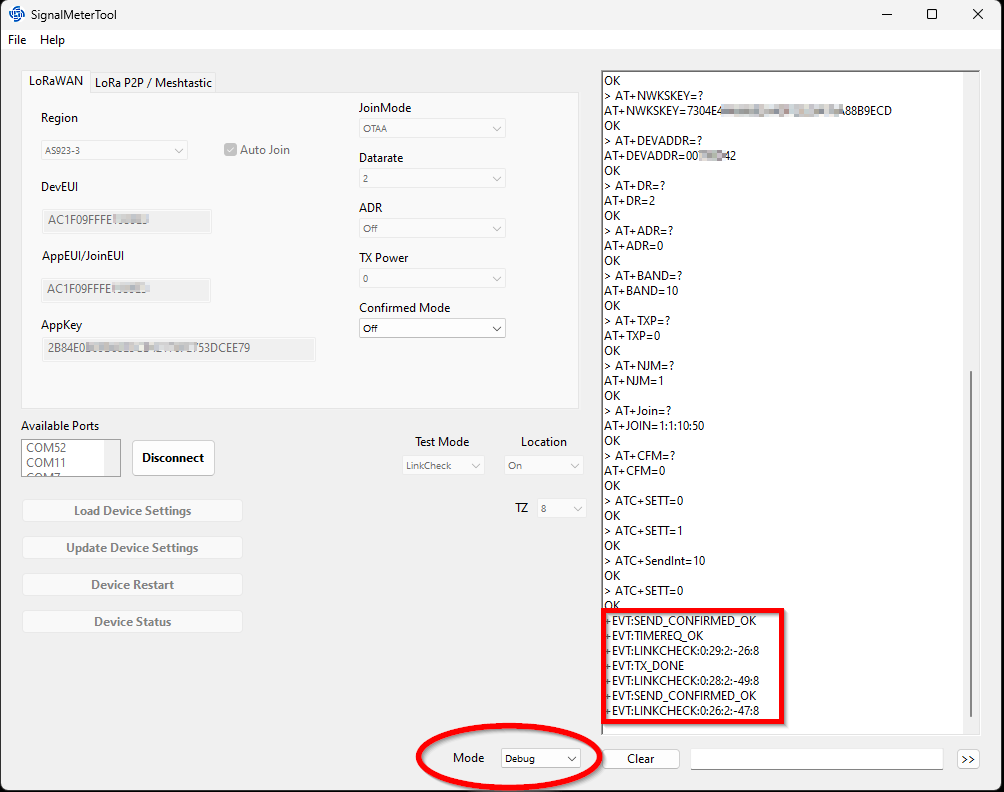
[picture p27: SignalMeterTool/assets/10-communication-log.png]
Communication Logs
 

----

### About the Application
This application was designed using [Xojo](https://xojo.com/), a cross-platform App Development Platform.
the project for this application can be found in the [SignalMeterTool/Project](./Project) folder.

This application is licensed under MIT.

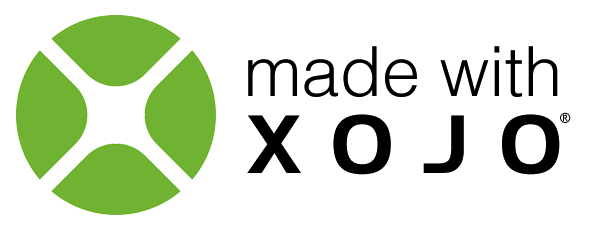
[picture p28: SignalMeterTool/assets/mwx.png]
Xojo
 

----
----

# LoRa® is a registered trademark or service mark of Semtech Corporation or its affiliates. 

# LoRaWAN® is a licensed mark.

----
----

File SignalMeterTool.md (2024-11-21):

# Signal Meter Tool

As an alternative tool to setup the RAK10706 Signal Meter for LoRa, the SignalMeter Tool is available.     
It is a simple to use tool that provides to setup the different functions of the RAK10706 SignalMeter:
- Choose test mode
- Set the test interval
- Enable/Disable location tracking
- Set LoRaWAN region
- Get/set the LoRaWAN credentials (required to register the device in the LoRaWAN server)
- Set LoRaWAN Join mode, data rate, ADR, TX power
- Set LoRa P2P frequency, SF, BW, CR, preamble length and TX power
- If the device has RTC
   - get and adjust the RTC time and date
- If the device has a SD card
   - set the timezone for the log date/time
   - read the log files (can take very long time, it is recommended to take out the SD card and read the files on a computer instead)
   - delete all log files

### ⚠️ Communication errors
If the connection between the computer and the device is interrupted, it is necessary to restart both the tool and the device to ensure a proper restart.

----

## Installation

# ⚠️ These tools are not officially supported by RAKwireless and are provided as is.     

### Windows
For Windows an installer is available in the [SignalMeterTool-Windows](./SignalMeterTool/Windows) folder.

----

### macOS
For macOS (not fully tested), the application is in a zipped file in the [SignalMeterTool-macOS](./SignalMeterTool/macOS) folder.     
The app is not signed by Apple and you might need to run _**codesign.sh**_ once the application is installed.

----

### Linux
Only partly tested on Ubuntu. The application is in a zipped file in the [SignalMeterTool-Linux](./SignalMeterTool/Linux) folder.     
It was required to manually give access to the USB port with shell commands. 

----

## Start connection to the device

1) Connect the RAK10706 over Serial to the computer
2) Select the COM port to which the device is connected
   - If multiple USB devices are connected that provide a serial connection, it is recommended to remove the other devices.    
   - ⚠️ If the RAK10706 is connected to the computer _**after**_ the application was started, use the refresh icon to get the new port list.
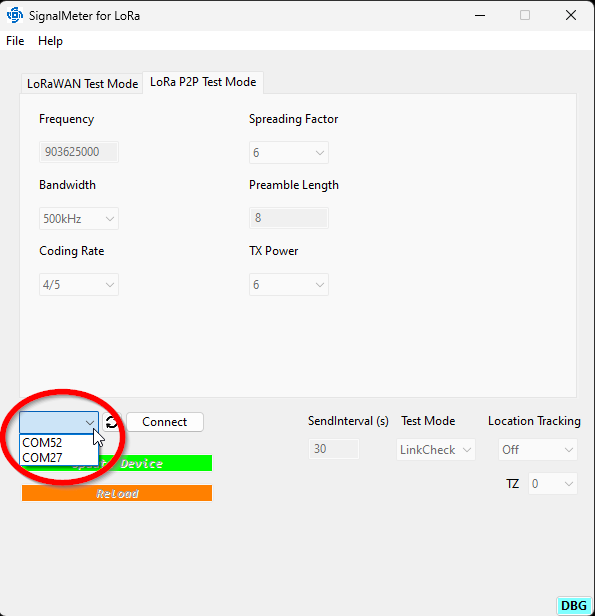
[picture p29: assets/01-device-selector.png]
USB ports


   - If the port of the RAK10706 is known, select this port

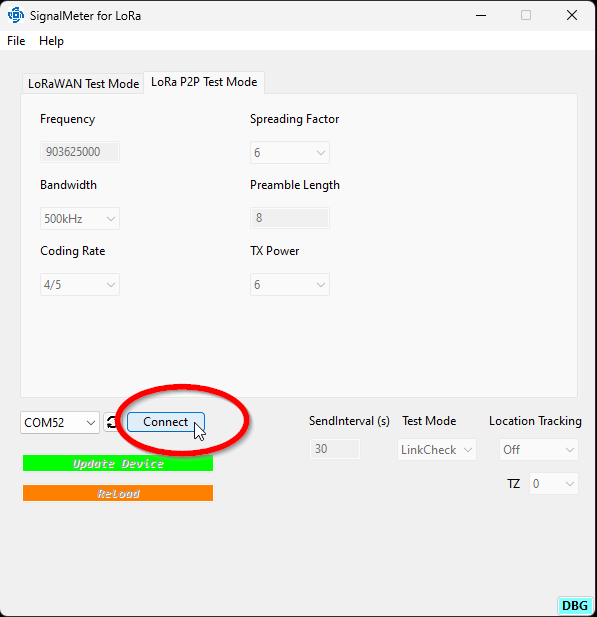
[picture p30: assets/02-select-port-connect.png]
Select port


   - If the device on the selected port is not a RAK10706, a warning will be displayed:

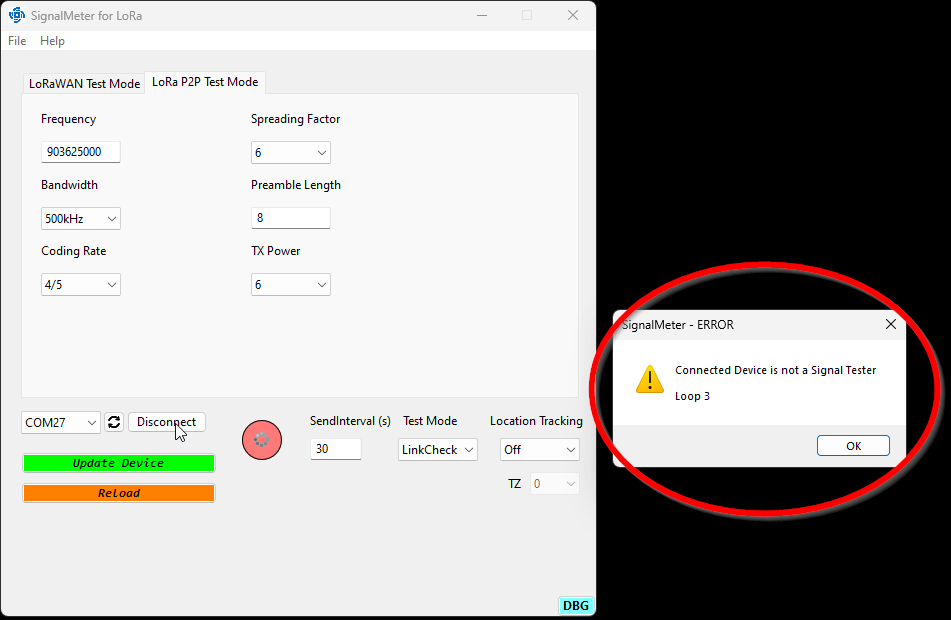
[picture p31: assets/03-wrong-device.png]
Warning: Not a RAK10706


   - In this case change the port and retry to connect.

⚠️ Communication between the application and the device is indicated with a rotating BUSY icon. While the BUSY icon is visible, control items in the application are disabled (beside of _**Disconnect**_).    
Do not disconnect the device while the communication is ongoing, or the device setup might be incomplete.

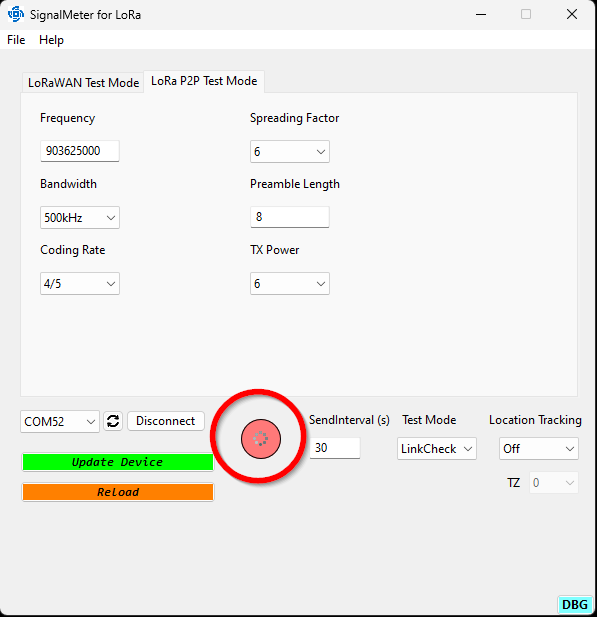
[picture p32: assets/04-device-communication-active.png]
Communication active


3) Once the device connection is established, the UI of the SignalMeter Tool will change, depending on the available features and settings.

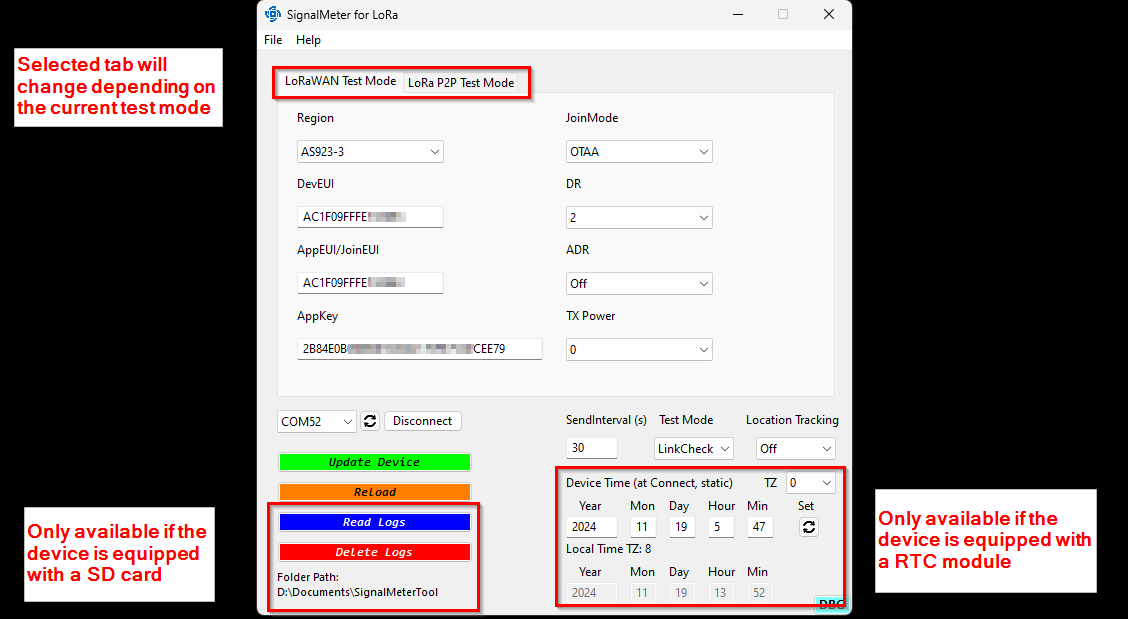
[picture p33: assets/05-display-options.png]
Display Options


----

## User Interface overview

### The top part (1) of the display is showing the LoRa P2P or LoRaWAN settings. 
⚠️ The content is changing depending on the current device settings and can show 
- LoRaWAN settings for OTAA Join Mode
- LoRaWAN settings for ABP Join Mode
- LoRa P2P settings

### The bottom left part (2) is showing options to
- Send new settings to the device (Update Device)
- Reload current settings from the device (Reload)
- If a SD card is present
   - Read the test log files from the device and save them as .CSV files
   - Delete all log files from the device
   - The folder path where the log files are saved to.

### The middle left part (3) shows the device test settings
- Send interval for the test packets
- Test mode
   - LinkCheck for basic LoRaWAN test mode without an back-end server
   - LoRa P2P test mode
   - FieldTester modes (compatible only, does not provide all Field Tester functions, requires an backend setup)

### The bottom right part (4) is only shown if a RTC module is present
- Show current date and time on the device
- Set the timezone to have the correct time/date in the log files
- Computer current timezone and date time
- _**Set**_ button to synchronize the time on the device with the computer time

⚠️ The device time is the time at the connection to the device. It is not updated dynamically.

<center>Display Details</center>

### Developer button
The small blue _**DBG**_ button on the bottom left side is opening an additional window that shows the communication between the device and the application:

<center>Debug output</center>

----

## Setup for LoRaWAN OTAA Join Mode

⚠️ LoRaWAN OTAA Join Mode and LinkCheck test method are the factory settings.

This setup is only availble when the device is in _**LinkCheck**_ or _**Field Tester**_ test modes.    

⚠️ Important is to set the LoRaWAN region for the device to be able to communicate with gateways and LoRaWAN servers.    

The LoRaWAN DevEUI, AppEUI (JoinEUI) and AppKey are preset by RAKwireless with unique values during the production. There are two options:
- (Recommended) Use the preset EUI's and Key to register the device on a LoRaWAN server (Chirpstack, TTN, Actility, ....) 
- Get EUI's and Key from the the LoRaWAN server and change the values here.

In addition, the TX power for the uplinks and datarate for the uplinks can be set here and adaptive datarate can be enabled or disabled.

⚠️ Changing the Join Mode will change the display content!

<center>OTAA settings</center>

----

## Setup for LoRaWAN ABP Join Mode

This setup is only availble when the device is in _**LinkCheck**_ or _**Field Tester**_ test modes.    

⚠️ Important is to set the LoRaWAN region for the device to be able to communicate with gateways and LoRaWAN servers.    

The LoRaWAN Device Address, Nw Session Key and App Session key must be set the same on the LoRaWAN server and in the device. Retrieve the keys and device address from your LoRaWAN server and use them here to setup the device with the correct values.

In addition, the TX power for the uplinks and datarate for the uplinks can be set here and adaptive datarate can be enabled or disabled.

⚠️ Changing the Join Mode will change the display content!

<center>ABP settings</center>

----

## Setup for LoRa P2P Mode

⚠️ Important in LoRa P2P test mode is that other devices are setup to the same settings, otherwise they cannot communicate with each other.    

Set the transmission parameters like frequency, bandwidth, coding rate, spreading factor, preamble length to the same values used by other LoRa P2P device that are used in the coverage testing.

<center>P2P settings</center>

----

## Setup Send Interval, Test Mode and Location Tracking

These settings define the test interval, the test mode and whether location tracking is used or not.

Send interval defines how many seconds are between two outgoing test uplinks.    

Test Mode switches between the different available test modes.    

⚠️ Changing the test mode does not immediately enforce a change. It is required to use the _**Update Button**_ to send the new setting to the device first. The device will reset once it received the update and the application will reconnect automatically.

Location tracking enables or disables the GNSS location chip in the device.

⚠️ When to enable or disable the GNSS location tracking:    
Location tracking works only outdoors. If the test is for coverage test indoors, the GNSS location tracking should be disabled. This will reduce power consumption of the device.    

<center>Test settings</center>

----

## Send setting to the device

Once the setup is finished, the device must be synced to the new settings with the _**Update Device**_ button.    
Pushing the button, will send all new settings to the device. The device will reset once it received the update and the application will reconnect automatically.     
While the settings are send to the device, the ongoing documentation is indicated with a rotating BUSY icon and the application UI is disabled.    

<center>Update device</center>

After the update is finished, the application UI will refresh with the new settings.    

----

## Setting the timezone

⚠️ These function is only available if the device is equipped with an SD Card module.    

If the device does not have an RTC module, it will retrieve the date and time from the LoRaWAN server with the TimeRequest command. The date and time sent by the LoRaWAN server is in GMT+0 format. To get the correct date and time in the log files, the device has to be setup with the correct timezone.

<center>Update device</center>

----

## Reading and erasing log files

⚠️ These functions are only available if the device is equipped with an SD Card module.    

### Reading the log files

With the _**Reading Logs**_ button, the log files saved on the SD card of the device can be read.    
The log files will be saved in .CSV (comma separated values) format. This format can be imported by most spread sheet applications like Excel.    
The RAK10706 Signal Meter splits the log into several small files to avoid file corruption during the tests. The files need to be joined together manually in the spread sheet application.    

During the download of the files, the rotating BUSY icon is shown.    
The path where the files are saved are shown below the buttons.

<center>Update device</center>

# ⚠️
_**Retrieving the log data over the USB port can take a long time, depending on the number and size of the log files.**_    
_**It is recommended to remove the SD card from the device and use a computer and a SD Card adapter to copy the log files. This method is much faster than reading out the files from the device**_
# ⚠️

After all log files are downloaded, the RAK10706 SignalTester will perform a reset and the application will automatically reconnect to it.

⚠️ If the log output is enabled with the blue _**DBG**_ button, the progress of the download can be seen in the application.    

<center>Update device</center>

----

### Erase the log files

The _**Delete Logs**_ button will erase all stored log files from the SD card of the RAK10706 SignalMeter.    

Before the data is erased, a confirmation window will be shown.    

<center>Update device</center>

----

## Setting the time and date

⚠️ These functions are only available if the device is equipped with an RTC module.    

The current date and time of the RTC and the used timezone are displayed in the application.    
As reference, the current computer date, time and timezone are shown below.    
The date and time can be changed manually or synced with the computer time using the _**Set**_ button.    
The device date and time will be updated by using the _**Update Device**_ button.    

<center>Update device</center>

----
----
----
# LoRa® is a registered trademark or service mark of Semtech Corporation or its affiliates.

# LoRaWAN® is a licensed mark.

----
----
----

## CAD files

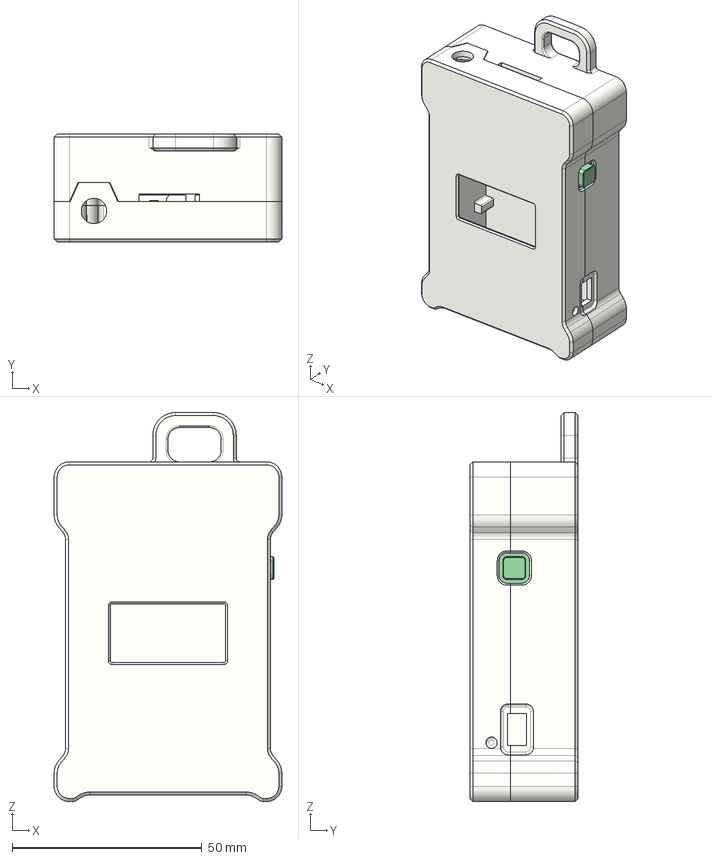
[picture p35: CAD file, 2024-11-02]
enclosure/Signal_Meter_V4_for-3D v1.step
60.0 x 28.5 x 102.5 mm
RAKU73020147
RAKU73020148
CAP

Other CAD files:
enclosure/Signal_Meter_V4_for-3D v1.f3d
enclosure/Signal_Meter_V4_for-3D v2.skp

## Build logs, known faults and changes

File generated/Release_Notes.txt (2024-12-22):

RAK10706 Signal Meter FW Release

========================= Version: V2.0.11 Release Note =========================
Date 22 December 2024

1. Add experimental Meshtastic support

========================= Version: V2.0.10 Release Note =========================
Date 05 December 2024

1. First release

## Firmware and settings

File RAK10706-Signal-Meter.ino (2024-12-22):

/**
 * @file RAK10706-Signal-Meter.ino
 * @author Bernd Giesecke (bernd@giesecke.tk)
 * @brief Simple signal meter for LoRa P2P and LoRaWAN
 * @version 0.2
 * @date 2024-11-18
 *
 * @copyright Copyright (c) 2024
 *
 */
#include "app.h"

/** Last RX SNR level*/
volatile int8_t last_snr = 0;
/** Last RX RSSI level*/
volatile int16_t last_rssi = 0;
/** Link check result */
volatile uint8_t link_check_state;
/** Demodulation margin */
volatile uint8_t link_check_demod_margin;
/** Number of gateways */
volatile uint8_t link_check_gateways;
/** Got linkcheck response? */
bool has_link_check = false;
/** fPort to use */
uint8_t fPort = 2;
/** Sent packet counter */
volatile int32_t packet_num = 0;
/** Lost packet counter (only LPW mode)*/
volatile int32_t packet_lost = 0;
/** Last RX data rate */
volatile uint8_t last_dr = 0;
/** TX fail reason (only LPW mode)*/
volatile int32_t tx_fail_status;
/** Packet Loss Rate (only FieldTester V2 mode) */
volatile float plr;

/** TX active flag (used for manual sending in FieldTester Mode and P2P mode) */
volatile bool tx_active = false;
/** Flag if TX is manually triggered */
volatile bool forced_tx = false;
/** Flag if DR sweeping is active */
volatile bool dr_sweep_active = false;

/** LoRa mode */
bool lorawan_mode = true;

/** Flag if OLED was found */
bool has_oled = false;
/** Buffer for OLED output */
char line_str[256];
/** Flag for display handler */
uint8_t display_reason;

/** Task Manager for button press */
MillisTaskManager mtmMain;

/** LoRaWAN packet (used for FieldTester Mode only) */
WisCayenne g_solution_data(255);

/** Buffer for FieldTester downlink */
uint8_t field_tester_pckg[32];

/** Flag for GNSS readings active */
bool gnss_active = false;

/** Flag if SD card was found */
bool has_sd = false;

/** Flag if new file is created */
bool has_file = false;

/** Flag if GNSS is working */
bool has_gnss = false;

/** Name of current log file */
char volatile file_name[] = "0000-log.csv";

/** Structure for result data */
volatile result_s result;

/** Flag if TimeReq succeeded */
uint8_t sync_time_status = 0;

/** Meshtastic receiver node */
uint32_t receiver_node = 0;
/** Meshtastic sender node */
uint32_t sender_node = 0;

/**
 * @brief Send a LoRaWAN packet
 *
 * @param data unused
 */
void send_packet(void *data)
{
	tx_active = true;
	ready_to_dump = false;

	if ((g_custom_parameters.test_mode == MODE_FIELDTESTER) || (g_custom_parameters.test_mode == MODE_FIELDTESTER_V2))
	{
		// Clear payload
		g_solution_data.reset();

		if (g_custom_parameters.location_on)
		{
			if (!gnss_active)
			{
				if (has_oled && !g_settings_ui)
				{
					oled_clear();
					if (g_custom_parameters.test_mode == MODE_FIELDTESTER)
					{
						oled_write_header((char *)"RAK FieldTester");
					}
					else
					{
						oled_write_header((char *)"RAK FieldTest V2");
					}
					oled_add_line((char *)"Start location acquisition");
				}

				// Check if we already have a sufficient location fix
				if (poll_gnss())
				{
					// Get gateway time
					if (sync_time_status == 0)
					{
						MYLOG("APP", "Request time");
						api.lorawan.timereq.set(1);
					}
					// Check if packet size fits DR
					if (!check_dr(g_custom_parameters.custom_packet_len))
					{
						return;
					}

					// Always send confirmed packet to make sure a reply is received
					MYLOG("GNSS", "Send from send_packet FieldTester poll success fPort %d", fPort);
					// Serial.println("+EVT:>>>>>>>>");
					if (!api.lorawan.send(g_solution_data.getSize(), g_solution_data.getBuffer(), fPort, true, 0))
					{
						MYLOG("APP", "LoRaWAN send returned error");
						tx_active = false;
						ready_to_dump = true;
					}
					// Increase sent packet number
					packet_num++;
				}
				else
				{
					if (forced_tx || dr_sweep_active) // Send immediately, with or without location
					{
						forced_tx = false;
						if (has_oled && !g_settings_ui)
						{
							sprintf(line_str, "Force TX w/o location");
							oled_add_line(line_str);
						}
						// If forced TX, send whether we have location or not 143050416, 1206306357
						if (g_custom_parameters.test_mode == MODE_FIELDTESTER_V2)
						{
							g_solution_data.addGNSS_T2(0, 0, (int16_t)packet_num);
						}
						else
						{
							g_solution_data.addGNSS_T(0, 0, 0, 1, 0);
						}

						// Get gateway time
						if (sync_time_status == 0)
						{
							MYLOG("GNSS", "Request time");
							api.lorawan.timereq.set(1);
						}

						// Check if packet size fits DR
						if (!check_dr(g_custom_parameters.custom_packet_len))
						{
							return;
						}

						MYLOG("GNSS", "Send from send_packet FieldTester forced fPort %d", fPort);
						// Serial.println("+EVT:>>>>>>>>");
						if (!api.lorawan.send(g_solution_data.getSize(), g_solution_data.getBuffer(), fPort, true, 0))
						{
							tx_active = false;
							MYLOG("GNSS", "LoRaWAN send returned error");
							ready_to_dump = true;
						}
						else
						{
							tx_active = true;
						}
						// Increase sent packet number
						packet_num++;
					}
					else // Wait for location fix
					{
						// Start checking for valid location
						// Set flag for GNSS active to avoid retrigger */
						gnss_active = true;
						g_solution_data.reset();
						check_gnss_counter = 0;
						// Max location aquisition time is half of send frequency
						check_gnss_max_try = g_custom_parameters.send_interval / 2 / 2500;
						// Reset satellites check values
						max_sat = 0;
						max_sat_unchanged = 0;
						// Start the timer
						api.system.timer.start(RAK_TIMER_3, 2500, NULL);
					}
				}
			}
			else
			{
				if (has_oled && !g_settings_ui)
				{
					oled_clear();
					if (g_custom_parameters.test_mode == MODE_FIELDTESTER)
					{
						oled_write_header((char *)"RAK FieldTester");
					}
					else
					{
						oled_write_header((char *)"RAK FieldTest V2");
					}
					oled_add_line((char *)"Acquisition ongoing");
				}

				MYLOG("APP", "GNSS already active");
			}
		}
		else
		{
			if (has_oled && !g_settings_ui)
			{
				oled_clear();
				if (g_custom_parameters.test_mode == MODE_FIELDTESTER)
				{
					oled_write_header((char *)"RAK FieldTester");
				}
				else
				{
					oled_write_header((char *)"RAK FieldTest V2");
				}
				oled_add_line((char *)"Indoor test");
			}
			// Location is switched off, send indoor test packet
			if (g_custom_parameters.test_mode == MODE_FIELDTESTER_V2)
			{
				g_solution_data.addGNSS_T2(0, 0, (int16_t)packet_num);
			}
			else
			{
				g_solution_data.addGNSS_T(0, 0, 0, 1.0, 0);
			}

			// Get gateway time
			if (sync_time_status == 0)
			{
				api.lorawan.timereq.set(1);
				MYLOG("APP", "Request time");
			}

			// Check if packet size fits DR
			if (!check_dr(g_custom_parameters.custom_packet_len))
			{
				return;
			}

			// Always send confirmed packet to make sure a reply is received
			MYLOG("APP", "Send from send_packet FieldTester location off fPort %d", fPort);
			// Serial.println("+EVT:>>>>>>>>");
			if (!api.lorawan.send(g_solution_data.getSize(), g_solution_data.getBuffer(), fPort, true, 0))
			{
				MYLOG("APP", "LoRaWAN send returned error");
				tx_active = false;
			}
			// Increase sent packet number
			packet_num++;
		}
	}
	else // LinkCheck or LoRa P2P
	{
		if (has_oled && !g_settings_ui)
		{
			oled_clear();
			oled_write_header((char *)"RAK Signal Meter");
			forced_tx = false;
		}

		g_solution_data.reset();

		if (api.lorawan.nwm.get())
		{
			if (api.lorawan.njs.get())
			{
				digitalWrite(LED_BLUE, HIGH);
				MYLOG("APP", "Send packet");
				if (dr_sweep_active)
				{
					oled_add_line((char *)"DR sweep sending");
				}
				else if (forced_tx)
				{
					oled_add_line((char *)"Forced sending");
				}
				else
				{
					oled_add_line((char *)"Start sending");
				}

				// Get gateway time
				if (sync_time_status == 0)
				{
					MYLOG("APP", "Request time");
					api.lorawan.timereq.set(1);
				}
				// Always send confirmed packet to make sure a reply is received
				if (g_custom_parameters.location_on)
				{
					if (!poll_gnss())
					{
						g_last_long = 0.0;
						g_last_lat = 0.0;
						g_solution_data.addGNSS_T(0, 0, 0, 0, 0);
					}

					// Check if packet size fits DR
					if (!check_dr(g_solution_data.getSize()))
					{
						return;
					}
					MYLOG("GNSS", "Send from send_packet LinkCheck location on fPort %d", fPort);
					if (!api.lorawan.send(g_solution_data.getSize(), g_solution_data.getBuffer(), fPort, true, 0))
					{
						tx_active = false;
						MYLOG("APP", "LoRaWAN send returned error");
						ready_to_dump = true;
					}
					// Increase sent packet number
					packet_num++;
				}
				else
				{
					// Check if packet size fits DR
					if (!check_dr(g_custom_parameters.custom_packet_len))
					{
						return;
					}
					MYLOG("GNSS", "Send from send_packet LinkCheck location off fPort %d", fPort);
					// Serial.println("+EVT:>>>>>>>>");
					if (!api.lorawan.send(g_custom_parameters.custom_packet_len, g_custom_parameters.custom_packet, fPort, true, 0))
					{
						tx_active = false;
						MYLOG("APP", "LoRaWAN send returned error");
						ready_to_dump = true;
					}
					// Increase sent packet number
					packet_num++;
				}
			}
			else
			{
				tx_active = false;
				MYLOG("APP", "Not joined, don't send packet");
				ready_to_dump = true;
			}
		}
		else
		{
			digitalWrite(LED_GREEN, HIGH);
			MYLOG("APP", "Send P2P packet");
			oled_add_line((char *)"Start sending");

			// Always send with CAD
			api.lora.psend(g_custom_parameters.custom_packet_len, g_custom_parameters.custom_packet, false); //, true);
			tx_active = true;
			// Increase sent packet number
			packet_num++;
		}
	}
}

/**
 * @brief Display handler
 *
 * @param reason 1 = RX packet display (only P2P mode)
 *               2 = TX failed display (only LPW LinkCheck mode)
 *               3 = Join failed (only LPW mode)
 *               4 = Linkcheck result display (only LPW LinkCheck mode)
 *               5 = Join success (only LPW mode)
 *               6 = FieldTester downlink packet (only FieldTester mode )
 *               7 = FieldTester no downlink packet (only FieldTester mode )
 *               8 = P2P TX finished (only P2P mode)
 */
void handle_display(void *reason)
{
	// Update date and time if synced with LNS
	if (sync_time_status == 1)
	{
		sync_time_status = 2;

		struct tm localtime;
		SysTime_t UnixEpoch = SysTimeGet();
		UnixEpoch.Seconds -= 18;												/*removing leap seconds*/
		UnixEpoch.Seconds += (int32_t)(g_custom_parameters.timezone * 60 * 60); // Make it GMT+8
		SysTimeLocalTime(UnixEpoch.Seconds, &localtime);
		MYLOG("APP", "LNS Time %d %d %d %d:%d:%d\n", localtime.tm_year + 1900, localtime.tm_mon + 1,
			  localtime.tm_mday, localtime.tm_hour,
			  localtime.tm_min, localtime.tm_sec);

		g_date_time.year = localtime.tm_year + 1900;
		g_date_time.month = localtime.tm_mon + 1;
		g_date_time.date = localtime.tm_mday;
		g_date_time.hour = localtime.tm_hour;
		g_date_time.minute = localtime.tm_min;
		g_date_time.second = localtime.tm_sec;
		if (has_rtc)
		{
			MYLOG("APP", "Sync RTC with LoRaWAN");
			set_rak12002(g_date_time.year, g_date_time.month, g_date_time.date, g_date_time.hour, g_date_time.minute, g_date_time.second);
			read_rak12002();
			MYLOG("APP", "After sync: %d %d %d %d:%d:%d\n", g_date_time.year, g_date_time.month,
				  g_date_time.date, g_date_time.hour,
				  g_date_time.minute, g_date_time.second);
		}
	}

	digitalWrite(LED_BLUE, LOW);
	digitalWrite(LED_GREEN, LOW);
	// Get the wakeup reason
	uint8_t *disp_reason = (uint8_t *)reason;

	// Check if we have a reason
	if (disp_reason == NULL)
	{
		MYLOG("APP", "Bug in code!");
		return;
	}

	switch (disp_reason[0])
	{
	case 1: // RX packet display (only P2P mode)
		prepare_oled_header();
		// MYLOG("APP", "RX_EVENT %d, disp_reason[0]);
		// RX event display
		if (has_sd)
		{
			if (has_rtc)
			{
				read_rak12002();
			}
			else
			{
				get_mcu_time();
			}
			result.year = g_date_time.year;
			result.month = g_date_time.month;
			result.day = g_date_time.date;
			result.hour = g_date_time.hour;
			result.min = g_date_time.minute;
			result.sec = g_date_time.second;
			result.mode = MODE_P2P;
			result.gw = 0;
			result.lat = g_last_lat;
			result.lng = g_last_long;
			result.min_rssi = 0;
			result.max_rssi = 0;
			result.rx_rssi = last_rssi;
			result.rx_snr = last_snr;
			result.min_dst = 0;
			result.max_dst = 0;
			result.demod = 0;
			result.lost = packet_lost;
			write_sd_entry();
		}
		if (has_oled && !g_settings_ui)
		{
			sprintf(line_str, "LoRa P2P mode");
			oled_write_line(0, 0, line_str);
			sprintf(line_str, "Received packets %d", packet_num);
			oled_write_line(1, 0, line_str);
			sprintf(line_str, "F %.3f", (api.lora.pfreq.get() / 1000000.0));
			oled_write_line(2, 0, line_str);
			sprintf(line_str, "SF %d", api.lora.psf.get());
			oled_write_line(3, 0, line_str);
			// 0 = 125, 1 = 250, 2 = 500, 3 = 7.8, 4 = 10.4, 5 = 15.63, 6 = 20.83, 7 = 31.25, 8 = 41.67, 9 = 62.5
			char bw_str[7];
			switch (api.lora.pbw.get())
			{
			case 0:
				sprintf(bw_str, "125");
				break;
			case 1:
				sprintf(bw_str, "250");
				break;
			case 2:
				sprintf(bw_str, "500");
				break;
			case 3:
				sprintf(bw_str, "7.8");
				break;
			case 4:
				sprintf(bw_str, "10.4");
				break;
			case 5:
				sprintf(bw_str, "15.63");
				break;
			case 6:
				sprintf(bw_str, "20.83");
				break;
			case 7:
				sprintf(bw_str, "31.25");
				break;
			case 8:
				sprintf(bw_str, "41.67");
				break;
			case 9:
				sprintf(bw_str, "62.5");
				break;
			default:
				sprintf(bw_str, "???");
				break;
			}
			sprintf(line_str, "BW %s", p_bw_menu[api.lora.pbw.get()]); // bw_str
			oled_write_line(3, 64, line_str);
			sprintf(line_str, "CR 4/%d", api.lora.pcr.get() + 5);
			oled_write_line(2, 64, line_str);
			sprintf(line_str, "RSSI %d", last_rssi);
			oled_write_line(4, 0, line_str);
			sprintf(line_str, "SNR %d", last_snr);
			oled_write_line(4, 64, line_str);
			oled_display();
		}
		MYLOG("APP", "LPW P2P mode");
		MYLOG("APP", "Packet # %d RSSI %d SNR %d", packet_num, last_rssi, last_snr);
		MYLOG("APP", "F %.3f SF %d BW %d",
			  (float)api.lora.pfreq.get() / 1000000.0,
			  api.lora.psf.get(),
			  (api.lora.pbw.get() + 1) * 125);
		break;
	case 2: // TX failed display (only LPW LinkCheck mode)
		prepare_oled_header();
		tx_active = false;

		if (has_sd)
		{
			if (has_rtc)
			{
				read_rak12002();
			}
			else
			{
				get_mcu_time();
			}
			result.year = g_date_time.year;
			result.month = g_date_time.month;
			result.day = g_date_time.date;
			result.hour = g_date_time.hour;
			result.min = g_date_time.minute;
			result.sec = g_date_time.second;
			result.mode = MODE_LINKCHECK;
			result.gw = 0;
			result.lat = g_last_lat;
			result.lng = g_last_long;
			result.min_rssi = 0;
			result.max_rssi = 0;
			result.rx_rssi = 0;
			result.rx_snr = 0;
			result.min_dst = 0;
			result.max_dst = 0;
			result.demod = 0;
			result.lost = packet_lost;
			result.tx_dr = api.lorawan.dr.get();
			write_sd_entry();
		}
		if (has_oled && !g_settings_ui)
		{
			sprintf(line_str, "LinkCheck Mode");
			oled_write_line(0, 0, line_str);
			sprintf(line_str, "TX Error ", tx_fail_status);
			oled_write_line(2, 0, line_str);
			switch (tx_fail_status)
			{
			case RAK_LORAMAC_STATUS_ERROR:
				sprintf(line_str, "Service error");
				break;
			case RAK_LORAMAC_STATUS_TX_TIMEOUT:
				sprintf(line_str, "TX timeout");
				break;
			case RAK_LORAMAC_STATUS_RX1_TIMEOUT:
				sprintf(line_str, "RX1 timeout");
				break;
			case RAK_LORAMAC_STATUS_RX2_TIMEOUT:
				sprintf(line_str, "RX2 timeout");
				break;
			case RAK_LORAMAC_STATUS_RX1_ERROR:
				sprintf(line_str, "RX1 error");
				break;
			case RAK_LORAMAC_STATUS_RX2_ERROR:
				sprintf(line_str, "RX2 error");
				break;
			case RAK_LORAMAC_STATUS_JOIN_FAIL:
				sprintf(line_str, "Join failed");
				break;
			case RAK_LORAMAC_STATUS_DOWNLINK_REPEATED:
				sprintf(line_str, "Dowlink frame error");
				break;
			case RAK_LORAMAC_STATUS_TX_DR_PAYLOAD_SIZE_ERROR:
				sprintf(line_str, "Payload size error");
				break;
			case RAK_LORAMAC_STATUS_DOWNLINK_TOO_MANY_FRAMES_LOSS:
				sprintf(line_str, "Fcnt loss error");
				break;
			case RAK_LORAMAC_STATUS_ADDRESS_FAIL:
				sprintf(line_str, "Adress error");
				break;
			case RAK_LORAMAC_STATUS_MIC_FAIL:
				sprintf(line_str, "MIC error");
				break;
			case RAK_LORAMAC_STATUS_MULTICAST_FAIL:
				sprintf(line_str, "Multicast error");
				break;
			case RAK_LORAMAC_STATUS_BEACON_LOCKED:
				sprintf(line_str, "Beacon locked");
				break;
			case RAK_LORAMAC_STATUS_BEACON_LOST:
				sprintf(line_str, "Beacon lost");
				break;
			case RAK_LORAMAC_STATUS_BEACON_NOT_FOUND:
				sprintf(line_str, "Beacon not found");
				break;
			default:
				sprintf(line_str, "Unknown error");
				break;
			}
			oled_write_line(4, 0, line_str);
			oled_display();
		}
		break;
	case 3: // Join failed(only LPW mode)
		prepare_oled_header();
		// MYLOG("APP", "JOIN_ERROR %d\n", disp_reason[0]);
		if (has_oled && !g_settings_ui)
		{
			switch (g_custom_parameters.test_mode)
			{
			case MODE_LINKCHECK:
				oled_write_line(0, 0, (char *)"LinkCheck mode");
				break;
			case MODE_FIELDTESTER:
				oled_write_line(0, 0, (char *)"FieldTester mode");
				break;
			case MODE_FIELDTESTER_V2:
				oled_write_line(0, 0, (char *)"FieldTester V2 mode");
				break;
			}
			sprintf(line_str, "Test interval  %lds", g_custom_parameters.send_interval / 1000);
			oled_write_line(1, 0, line_str);
			oled_write_line(2, 0, (char *)" ");
			sprintf(line_str, "Join failed");
			oled_write_line(3, 0, line_str);
			oled_write_line(4, 0, (char *)" ");
			oled_display();
		}
		break;
	case 4: // Linkcheck result display(only LPW LinkCheck mode)
		prepare_oled_header();
		// MYLOG("APP", "LINK_CHECK %d\n", disp_reason[0]);
		// LinkCheck result event display
		if (has_sd)
		{
			if (has_rtc)
			{
				read_rak12002();
			}
			else
			{
				get_mcu_time();
			}
			result.year = g_date_time.year;
			result.month = g_date_time.month;
			result.day = g_date_time.date;
			result.hour = g_date_time.hour;
			result.min = g_date_time.minute;
			result.sec = g_date_time.second;
			result.mode = MODE_LINKCHECK;
			result.gw = link_check_gateways;
			result.lat = g_last_lat;
			result.lng = g_last_long;
			result.min_rssi = last_rssi;
			result.max_rssi = last_rssi;
			result.rx_rssi = last_rssi;
			result.rx_snr = last_snr;
			result.min_dst = 0;
			result.max_dst = 0;
			result.demod = link_check_demod_margin;
			result.lost = packet_lost;
			result.tx_dr = api.lorawan.dr.get();
			write_sd_entry();
		}
		if (has_oled && !g_settings_ui)
		{
			sprintf(line_str, "LPW LinkCheck %s", link_check_state == 0 ? "OK" : "NOK");
			oled_write_line(0, 0, line_str);
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
void loop(void)
{
	// api.system.sleep.all(100);
	if (pressCount != 0)
	{
		mtmMain.Running(millis());
	}
}

/**
 * @brief Set the module for LoRaWAN LinkCheck testing
 *
 */
void set_linkcheck(void)
{
	MYLOG("APP", "Found LinkCheck Mode");
	lorawan_mode = true;
	if (api.lora.nwm.get())
	{
		// If in LoRa P2P mode, switch of RX
		api.lora.precv(0);
	}
	// Force LoRaWAN mode (might cause restart)
	api.lorawan.nwm.set();
	// Register callbacks
	api.lorawan.registerRecvCallback(recv_cb_lpw);
	api.lorawan.registerSendCallback(send_cb_lpw);
	api.lorawan.registerJoinCallback(join_cb_lpw);
	api.lorawan.registerLinkCheckCallback(linkcheck_cb_lpw);
	api.lorawan.registerTimereqCallback(timereq_cb_lpw);
	// Set unconfirmed packet mode
	api.lorawan.cfm.set(false);
	// Enable LinkCheck
	api.lorawan.linkcheck.set(2);
	//  (Removed, because problem in production)
	// api.lorawan.join(1, 1, 10, 50);

	if (g_custom_parameters.location_on)
	{
		// Enable GNSS module
		digitalWrite(WB_IO2, HIGH);
	}
	else
	{
		// Disable GNSS module
		digitalWrite(WB_IO2, LOW);
	}
	fPort = 2;
}

/**
 * @brief Set the module for LoRa P2P testing
 *
 */
void set_p2p(void)
{
	MYLOG("APP", "Found P2P Mode");
	lorawan_mode = false;

	api.lora.precv(0);

	// Force LoRa P2P mode (might cause restart)
	if (!api.lora.nwm.set())
	{
		MYLOG("APP", "Failed to set P2P Mode");
	}
	// Register callbacks
	api.lora.registerPRecvCallback(recv_cb_p2p);
	api.lora.registerPSendCallback(send_cb_p2p);
	// Enable RX mode
	api.lora.precv(65533);
	if (g_custom_parameters.location_on)
	{
		// Enable GNSS module
		digitalWrite(WB_IO2, HIGH);
	}
	else
	{
		// Disable GNSS module
		digitalWrite(WB_IO2, LOW);
	}
}

/**
 * @brief Set the module into FieldTester Mode
 *
 */
void set_field_tester(void)
{
	lorawan_mode = true;
	if (api.lora.nwm.get())
	{
		// If in LoRa P2P mode, switch of RX
		api.lora.precv(0);
	}
	// Force LoRaWAN mode (might cause restart)
	api.lorawan.nwm.set();
	// Register callbacks
	api.lorawan.registerRecvCallback(recv_cb_lpw);
	api.lorawan.registerSendCallback(send_cb_lpw);
	api.lorawan.registerJoinCallback(join_cb_lpw);
	api.lorawan.registerLinkCheckCallback(linkcheck_cb_lpw);
	api.lorawan.registerTimereqCallback(timereq_cb_lpw);
	// Set unconfirmed packet mode
	api.lorawan.cfm.set(false);
	// Disable LinkCheck
	api.lorawan.linkcheck.set(2);
	//  (Removed, because problem in production)
	// api.lorawan.join(1, 1, 10, 50);
	if (g_custom_parameters.location_on)
	{
		// Enable GNSS module
		digitalWrite(WB_IO2, HIGH);
	}
	fPort = 1;
}

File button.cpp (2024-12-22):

/**
 * @file button.cpp
 * @author Bernd Giesecke (bernd@giesecke.tk)
 * @brief Button handler
 * @version 0.2
 * @date 2024-11-18
 *
 * @copyright Copyright (c) 2024
 *
 */
#include "app.h"
#include "udrv_dfu.h"

/** Button press time value */
volatile static time_t pressTime = 0;

/** Number of clicks counter */
volatile uint8_t pressCount = 0;

/** Timestamp for first button press event */
static time_t firstPressTime = 0;

/** Flag if UI is active or not */
bool g_settings_ui = false;
/** Current selected menu */
uint8_t sel_menu = 0;
/** Flag if changes require a restart */
bool restart_required = false;
/** Buffer for original settings */
custom_param_s g_last_settings;
/** Buffer of DR changes */
uint8_t ui_last_dr = 0;
/** Highest possible DR, depends on LoRaWAN region */
uint8_t ui_max_dr = 0;
/** Lowest possible DR, depends on LoRaWAN region */
uint8_t ui_min_dr = 0;
/** Selected LoRaWAN region */
uint8_t ui_last_band = 0;
/** Selected ADR status */
uint8_t ui_last_adr = 0;
/** Buffer for TX power changes */
uint8_t ui_last_tx = 0;
/** Highest possible TX, depends on LoRaWAN region */
uint8_t ui_max_tx = 0;
/** Lowest possible TX, depends on LoRaWAN region */
uint8_t ui_min_tx = 0;
/** Buffer for P2P frequency selection */
uint32_t ui_p2p_freq = 0;
/** Buffer for P2P SF selection */
uint8_t ui_p2p_sf = 0;
/** Buffer for P2P BW selection */
uint8_t ui_p2p_bw = 0;
/** Buffer for P2P CR selection */
uint8_t ui_p2p_cr = 0;
/** Buffer for P2P TX power selection */
uint8_t ui_p2p_tx = 0;

/** Content of top level menu */
char *top_menu[] = {"Back", "Info", "Device Settings", "Mode", "LoRa Setting"};
/** Size of top level menu */
uint8_t top_menu_len = 5;

/** Content for menus with only "Back" */
char *back_menu[] = {"Back"};
/** Size fo "Back" only menus */
uint8_t back_menu_len = 1;

/** Content of device settings menu */
char *settings_menu[] = {"Back", "Interval", "Location", "Display Saver"};
/** Size of device settings menu */
uint8_t settings_menu_len = 4;

/** Content of test mode menu */
char *mode_menu[] = {"Back", "LPW LinkCheck", "P2P", "FieldTester", "FieldTester V2"};
/** Size of test mode menu */
uint8_t mode_menu_len = 5;

/** Content of P2P settings menu */
char *settings_p2p_menu[] = {"Back", "Freq", "SF", "BW", "CR", "TX"};
/** Size of P2P settings menu */
uint8_t settings_p2p_menu_len = 6;

/** Content of LoRaWAN settings menu */
char *settings_lpw_menu[] = {"Back", "ADR", "DR", "TX", "Region"};
/** Size of LoRaWAN settings menu */
uint8_t settings_lpw_menu_len = 5;

/** Table with P2P bandwidths */
char *p_bw_menu[] = {"125", "250", "500", "62.5", "41.67", "31.25", "20.83", "15.63", "10.4", "7.8"};

/**
 * @brief Initialize button handler
 *     Register interrupt handler
 *     Register with millis task manager
 *
 * @return true
 * @return false
 */
bool buttonInit(void)
{
	pinMode(BUTTON_INT_PIN, INPUT_PULLUP);
	attachInterrupt(BUTTON_INT_PIN, buttonIntHandle, FALLING);

	mtmMain.Register(handle_button, 100); // Process button data every 100ms.

	return true;
}

/**
 * @brief Button interrupt handler
 *
 */
void buttonIntHandle(void)
{
	pressTime = millis();
	if ((millis() - firstPressTime) > 200) // for button debounce.
	{
		firstPressTime = millis();
		pressCount += 1;
	}
	MYLOG("BTN", "pressCount = %d", pressCount);
}

/**
 * @brief Button Status handler
 *
 * @return uint8_t button status, number of clicks or long press detection
 */
uint8_t getButtonStatus(void)
{
	uint8_t lowCount = 0;
	if (((millis() - pressTime) > 3000) && (digitalRead(BUTTON_INT_PIN) == LOW) && (pressCount >= 1))
	{
		return LONG_PRESS;
	}

	if (((millis() - pressTime) >= 400) && (pressCount == 1) && (digitalRead(BUTTON_INT_PIN) == HIGH))
	{
		uint8_t highCount = 0;
		for (uint8_t i; i < 200; i++)
		{
			if (digitalRead(BUTTON_INT_PIN) == HIGH)
				highCount++;
			delay(1);
		}
		if (highCount > 198) // Have no option but to.
		{
			return SINGLE_CLICK;
		}
	}

	if (((millis() - pressTime) >= 400) && (pressCount == 2) && (digitalRead(BUTTON_INT_PIN) == HIGH))
	{
		uint8_t highCount = 0;
		for (uint8_t i; i < 200; i++)
		{
			if (digitalRead(BUTTON_INT_PIN) == HIGH)
				highCount++;
			delay(1);
		}
		if (highCount > 198) // Have no option but to.
		{
			return DOUBLE_CLICK;
		}
	}

	if (((millis() - pressTime) >= 600) && (pressCount == 3))
	{
		uint8_t highCount = 0;
		for (uint8_t i; i < 200; i++)
		{
			if (digitalRead(BUTTON_INT_PIN) == HIGH)
				highCount++;
			delay(1);
		}
		if (highCount > 198) // Have no option but to.
		{
			return TRIPPLE_CLICK;
		}
	}

	if (((millis() - pressTime) >= 800) && (pressCount == 4))
	{
		uint8_t highCount = 0;
		for (uint8_t i; i < 200; i++)
		{
			if (digitalRead(BUTTON_INT_PIN) == HIGH)
				highCount++;
			delay(1);
		}
		if (highCount > 198) // Have no option but to.
		{
			return QUAD_CLICK;
		}
	}

	if (((millis() - pressTime) >= 1200) && (pressCount == 5))
	{
		uint8_t highCount = 0;
		for (uint8_t i; i < 200; i++)
		{
			if (digitalRead(BUTTON_INT_PIN) == HIGH)
				highCount++;
			delay(1);
		}
		if (highCount > 198) // Have no option but to.
		{
			return FIVE_CLICK;
		}
	}

	if (((millis() - pressTime) >= 1400) && (pressCount == 6))
	{
		uint8_t highCount = 0;
		for (uint8_t i; i < 200; i++)
		{
			if (digitalRead(BUTTON_INT_PIN) == HIGH)
				highCount++;
			delay(1);
		}
		if (highCount > 198) // Have no option but to.
		{
			return SIX_CLICK;
		}
	}
	if (((millis() - pressTime) >= 1600) && (pressCount == 7))
	{
		uint8_t highCount = 0;
		for (uint8_t i; i < 200; i++)
		{
			if (digitalRead(BUTTON_INT_PIN) == HIGH)
				highCount++;
			delay(1);
		}
		if (highCount > 198) // Have no option but to.
		{
			return SEVEN_CLICK;
		}
	}
	return BUTTONSTATE_NONE;
}
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

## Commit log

2024-11-02 Add the code
    [Signal_Meter_V4_for-3D v1.f3d, Signal_Meter_V4_for-3D v1.step, Signal_Meter_V4_for-3D v2.skp]
2024-11-05 Rename INO file, correct firmware version, change log output
    [RAK10706-Signal-Meter.ino, custom_at.cpp, sd-card.cpp]
2024-11-09 Improvements for Desktop App, Fix Field Tester V2
    [RAK10706-Signal-Meter.ino, button.cpp, custom_at.cpp]
2024-11-11 Add LinkCheck to FieldTester, fix blank screen
    [RAK10706-Signal-Meter.ino, gnss.cpp]
2024-11-15 Improve log dump over UART
2024-11-18 Update .gitignore, arduino.json, and 20 more files...
